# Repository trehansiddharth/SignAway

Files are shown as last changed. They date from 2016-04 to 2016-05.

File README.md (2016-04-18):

# SignAway

SignAway is a completely handheld probe that you can swipe over two signatures to algorithmically verify that they came from the same person. It is my final project for MIT's 6.115 course (Microcontrollers Lab).

## Directory Structure

- `./Background`: Background information on the algorithms used, such as SLAM and neural networks for signature verification.
- `./Datasheets`: Datasheets for the electronic components.
- `./Designs`: Schematics, board layouts, and CAD sketches for hardware.
- `./Logs`: Pictures, log files, and notes taken during development of SignAway to keep track of things.
- `./Source`: Source code running on the 2051 and PSoC.

## Disclaimer

Right now this is a work in progress. The deadline for completion is the end of May.

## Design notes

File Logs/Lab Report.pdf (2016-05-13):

Siddharth Trehan | 6.115: Final Project

## Goals

1. Make a hand-held probe that can verify whether two signatures match
2. I envision being able to swipe the probe over two signatures to verify whether the signature is correct
3. This probe will grab signatures using the camera/motion sensor provided by the ADNS-9800 laser mouse chip
4. The probe will also be able to provide a “forge” mode that allows the user to forge a pre-recorded signature by following directions on a set of LEDs or similar

## Introduction

I intend to build a portable, hand-held probe that allows you to scan over two signatures and verify whether or not they match. This can be used by, for example, lawyers and mailmen who wish to quickly and systematically verify that the same person signed two documents. The probe should be portable (self-contained, small, and lightweight) and easy to use (simply swipe over the two signatures to verify authenticity).
I am interested in this idea primarily because it is unique and because of the technology it integrates together. As a course 6-2, I not only like figuring out how hardware components fit together, but also how I can solve problems using innovative algorithmic techniques. Here, I get to learn about signature matching using artificial neural networks and different image vision techniques that can identify particular distinctive features in a signature. Ive also recently been interested in optical sensors (which provide both images and motion data) because they seem so widely applicable to anything that moves, so I wanted to learn how to use one with a microcontroller.
Finally, I believe this is a creative solution to the problem of not being able to verify the authenticity of signatures because it is easy-to-use and unintrusive in the daily work of people who might want to verify signatures. Signatures are used universally and on some very important documents. However, just based off of anecdotal evidence, the appropriate time and care is not being taken to verify the authenticity of signatures – often, in restaurants for example, even widely different signatures are taken to be from the same person without much thought. Given the popularity of optical character recognition (OCR) in solving other similar problems, such as automatically processing mailing addresses, I believe that such a combined hardware and software approach to this signature verification problem will be very effective.

## Hardware Overview

The following is a block diagram of the hardware for this project:

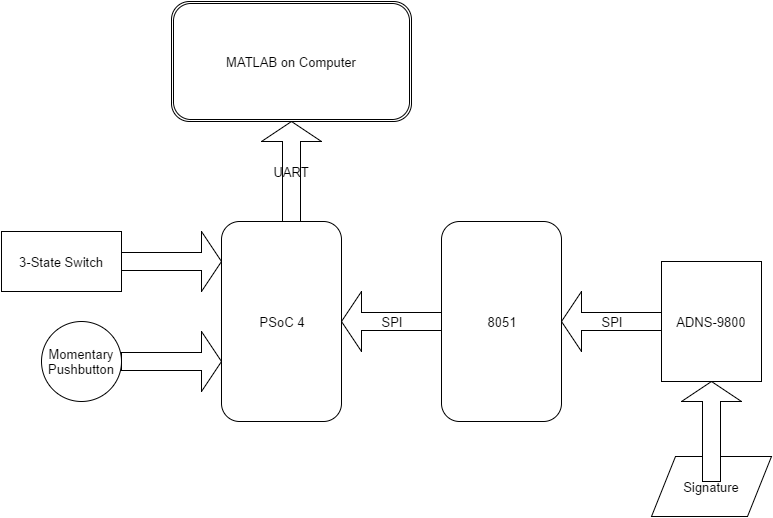
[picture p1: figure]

The ADNS-9800 chip captures the signature (using either motion detection or image capture, as described in the next section). This is communicated over SPI to the 8051, which will filter the signals from the 8051 and do some basic signal processing on them. It will then report only the relevant data to the PSoC. The PSoC also gets signals from a 3-state switch and a momentary pushbutton. The momentary pushbutton is to be held down when capturing a signature, and the position of the 3-state switch will determine what to do with the captured signature. The 3 modes available are “Record”, “Verify”, and “Forge”. The PSoC takes all this information and communicates it to a MATLAB program running on the computer. This MATLAB program is responsible for assimilating information from multiple signatures to either verify them or help you forge them.

## ADNS-9800 Sensor

The ADNS-9800 sensor is a laser mouse sensor that contains a very small camera to track motion over a surface. It works by taking pictures of the surface at a very high frame rate and calculating velocity by running optical flow. I picked this particular chip for its small size, good documentation, and ability to be used as a regular camera. It contains a number of registers, and the SPI protocol is used to read from and write to specific registers. There are three steps in getting the ADNS-9800 sensor working:

1. Wiring up the chip
2. Implementing the SPI protocol
3. Communicating with the chip’s registers

### Wiring up the chip

The following is a diagram and pin labeling of the ADNS-9800 chip:

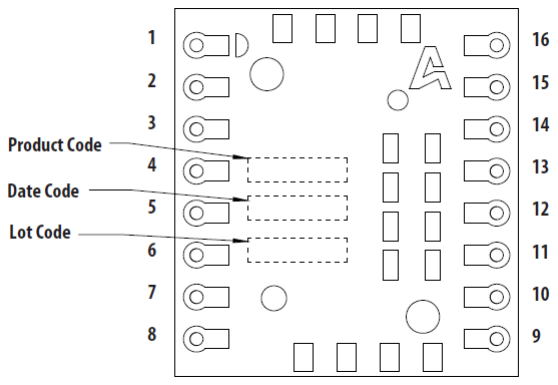
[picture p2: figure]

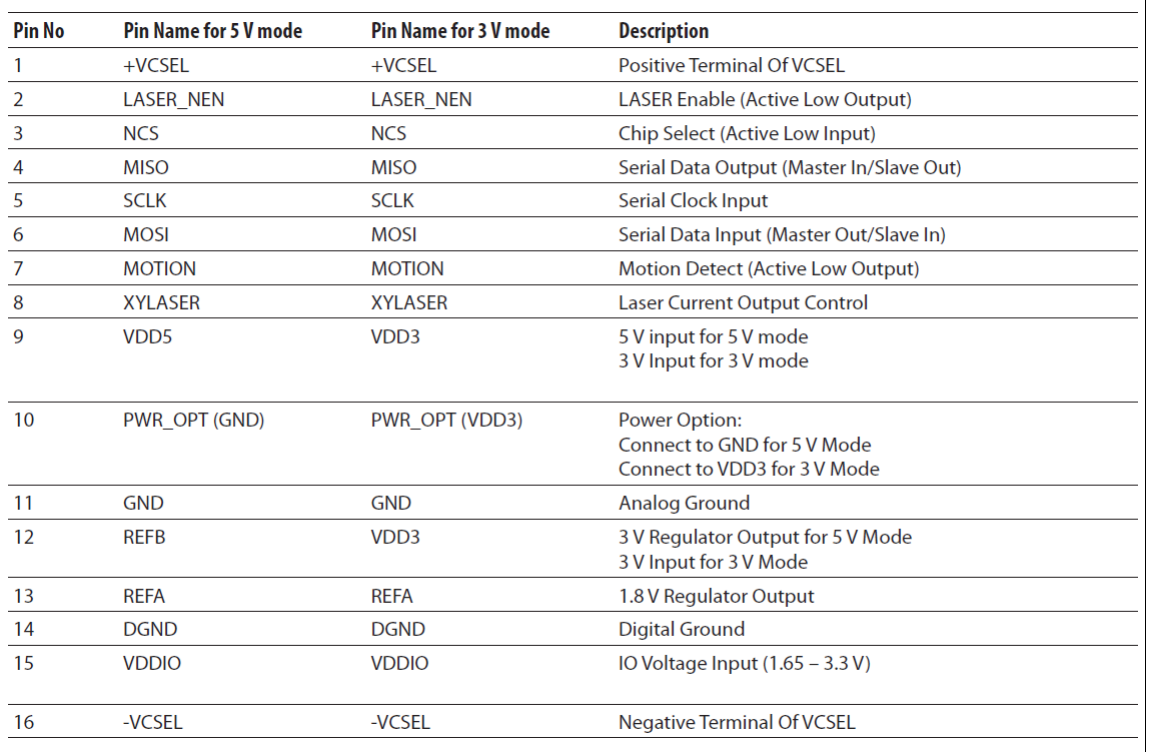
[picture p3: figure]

The ADNS-9800 can run in both 5V and 3V mode. In 5V mode, you provide 5V to VDD5 and GND to PWR OPT, and an internal regulator in the ADNS-9800 chip will provide 3V to provide voltage signals to the other pins. In 3V mode, you provide 3V to VDD3 and 3V to PWR OPT – you are responsible for providing the 3V yourself.

Pins 2-6 (NCS, MISO, SCLK, and MOSI) are used in SPI communication and can be left floating when just trying to get the chip wired up properly. Pin 7 (MOTION) is another pin used for communicating with the microcontroller – it goes high whenever the chip detects motion. In my informal testing when I got the chip wired up, MOTION would go high whenever I placed my finger on the lens. GND and DGND are both wired to ground, and in 3 V mode (which is what I would be using, and the reason will be explained later), VDD3 is wired to 3 V and PWR OPT and REFB are wired to VDD3. REFA (pin 13) is a 1.8 V regulator output and can be ignored.

This leaves the following pins: +VCSEL (pin 1), LASER NEN (pin 2), XYLASER (pin 8), VDDIO (pin 15), and -VCSEL (pin 16). LASER NEN and XYLASER relate to the operation of the laser, which has to be on in order for the mouse to illuminate the surface and capture images. A microcontroller communicating via SPI sets the appropriate register value to enable or disable the laser. This will set LASER NEN to low, which will activate a FET. This will allow XYLASER to draw power from the power supply and activate the laser. The other pins also serve different purposes and their wiring is described in more detail in the datasheet for the ADNS-9800.

The following is a schematic for the breakout board that I used for the ADNS-9800 chip:

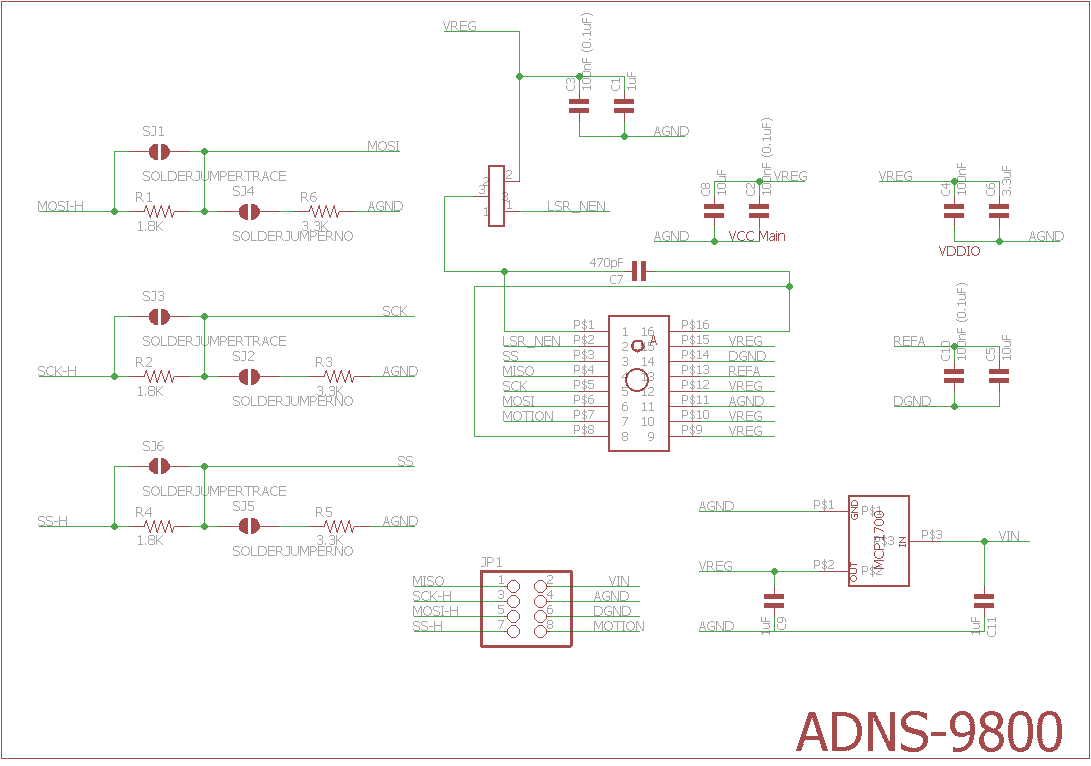
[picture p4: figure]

However, the issue here is that it cannot be used in 5 V mode because the voltage divider at MOSI-H, SCK-H, and SS-H do not actually divide unbuffered voltage. The pin of the 8051 contains an internal pull-up resistor which makes this voltage divider not divide voltage properly. To get around this I ran this breakout board in its native 3V and made a 5-to-3V level converter myself. The following is a schematic for the 5-to-3 TTL converter:

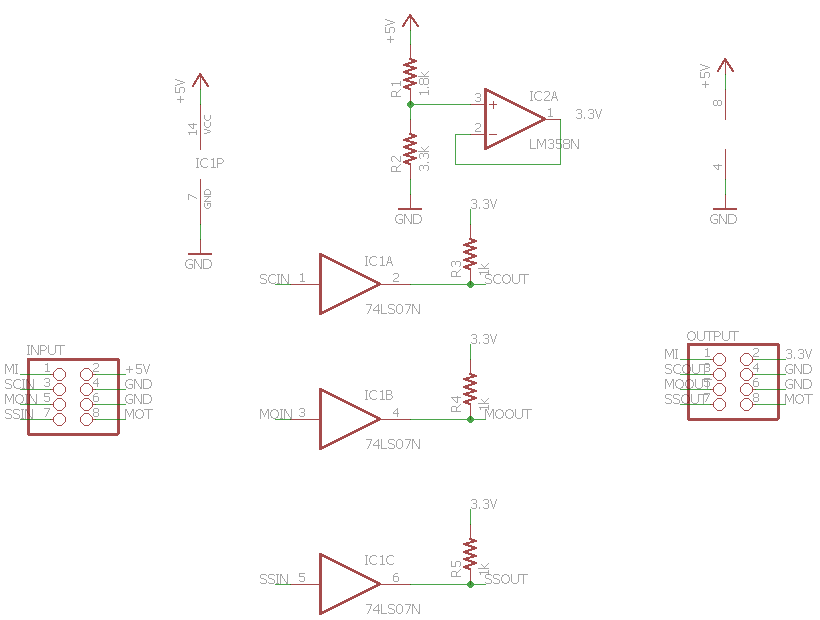
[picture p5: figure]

This contains an op-amp for converting 5V to 3V, and 3 buffers from the 74LS07 open-collector-output chip to perform the level conversion. This setup got the chip working at the right TTL level.

### Implementing the SPI protocol

The ADNS-9800 chip uses the SPI protocol with a max clock frequency of 2 MHz to communicate register values with a microcontroller. The data direction is MSB to LSB, an inactive SCLK signal is high, and data is read by the chip on rising clock edges. There are four types of commands:

1. Write operations: 16 bits are sent over MOSI. The first byte indicates the address of the register to write, and the second byte indicates the data to write to register. The first bit in the signal is 1 to indicate that it is a write command.
2. Read operations: 8 bits are sent over MOSI and 8 bits are received over MISO. The byte sent over MOSI indicates the address of the register to read (with the first bit a 0 to indicate reading), and the byte received over MISO is the data contained in the register. There is a also a required timing between sending the first byte and receiving the second.

3. Motion burst operations: In some cases reading each register corresponding to different kinds of motion individually using the read and write operations described above can be too slow. In motion burst operation, the MOTION BURST register is written to once. Then, when it is read using a normal read operation, 14 bytes are returned instead of 1, corresponding to the values of 14 different motion-related registers instead of just 1 at a time.
4. Image burst operations: Image burst mode allows you to download an entire frame that the chip has most recently captured. Since each frame is 30-by-30, this means transferring 900 8-bit pixel values over SPI. In this operation, you must first write to the FRAME CAPTURE register twice, read the MOTION bit register until the LSB is set, and then read 900 bytes from the PIXEL BURST register. This mode, however, disables motion tracking and requires a hardware reset. Therefore, switching back and forth between motion burst mode and image burst mode is not entirely practical.

Write operations

The following is a timing diagram for this operation:

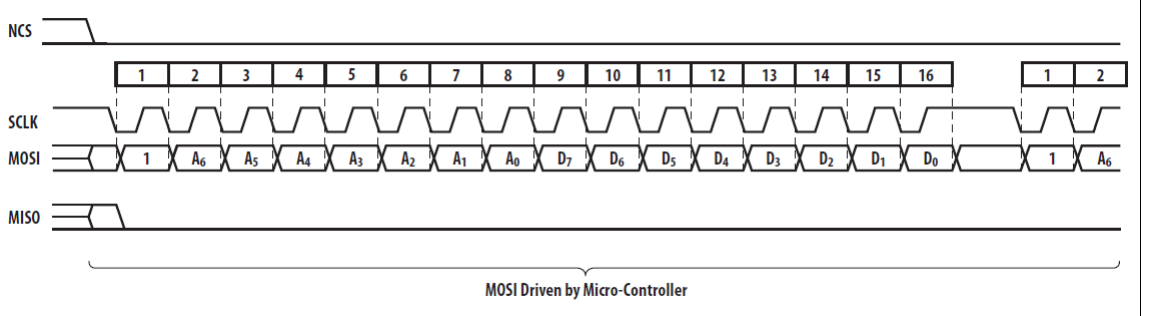
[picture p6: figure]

I implemented this by first writing the read spi and write spi subroutines on my microcontroller. These two subroutines drive an SCLK signal and either write a byte over MOSI or read a byte over MISO. They do not drive the SS pin low; that must be done in a higher level subroutine that takes into account which slave to select.

The following is an SCLK waveform I got on read spi:

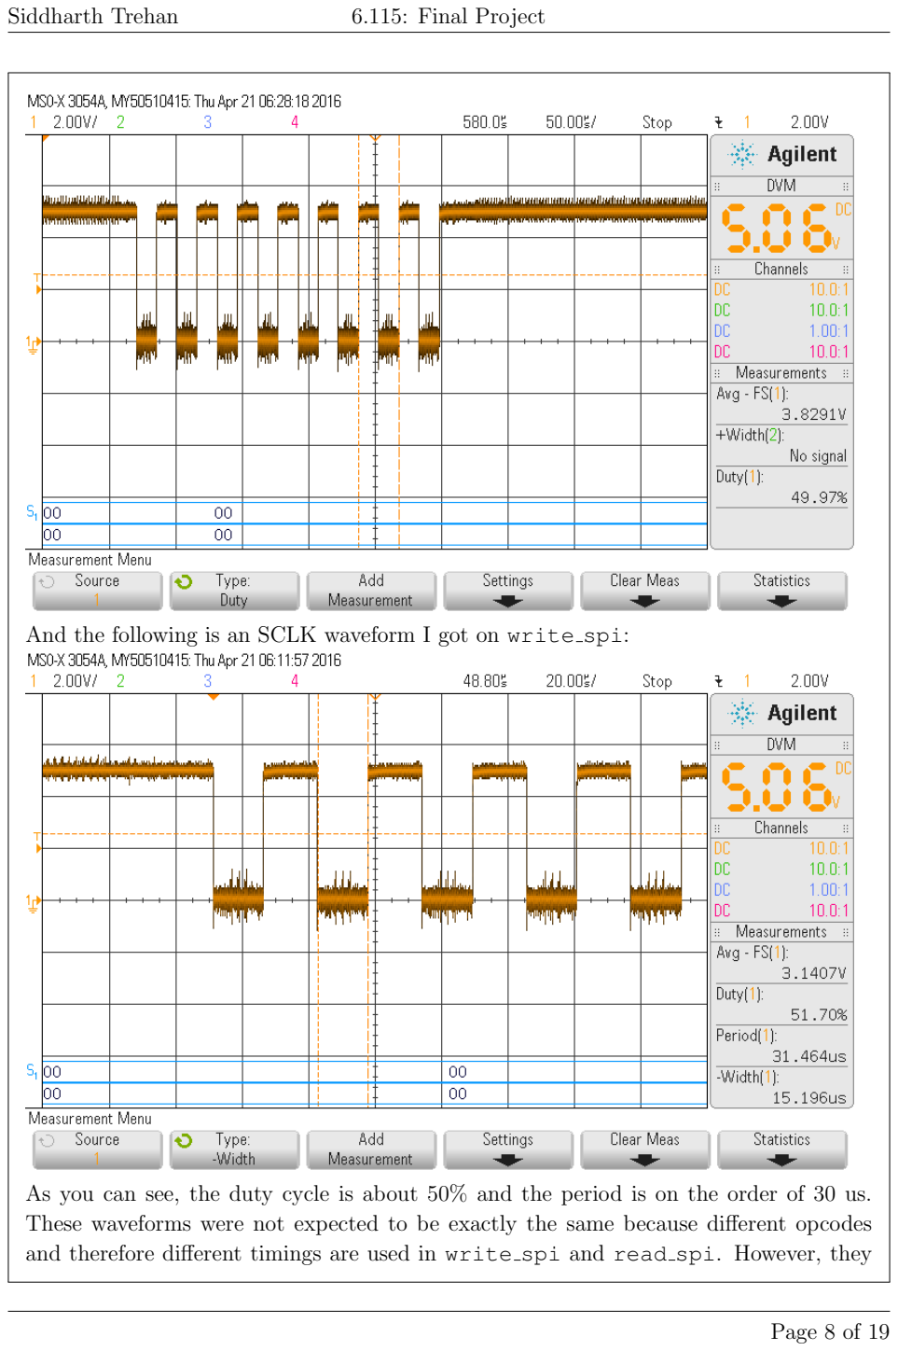
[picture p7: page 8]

And the following is an SCLK waveform I got on write spi:

As you can see, the duty cycle is about 50% and the period is on the order of 30 us. These waveforms were not expected to be exactly the same because different opcodes and therefore different timings are used in write spi and read spi. However, they do fit the requirements of the ADNS-9800 chip. I later modified these to have a smaller period by giving up on the duty cycle having to be 50% with the same result in terms of SPI operations but a slightly faster transfer rate.

Next, I implemented the write adns subroutine, which performs a write operation on the ADNS-9800 chip. It lowers NCS, does a write spi to write the register address over MOSI (with the MSB set to 1), then another write spi to write the register value over MOSI, and then finally raises NCS. I got the following waveforms for the SCLK and MOSI lines:

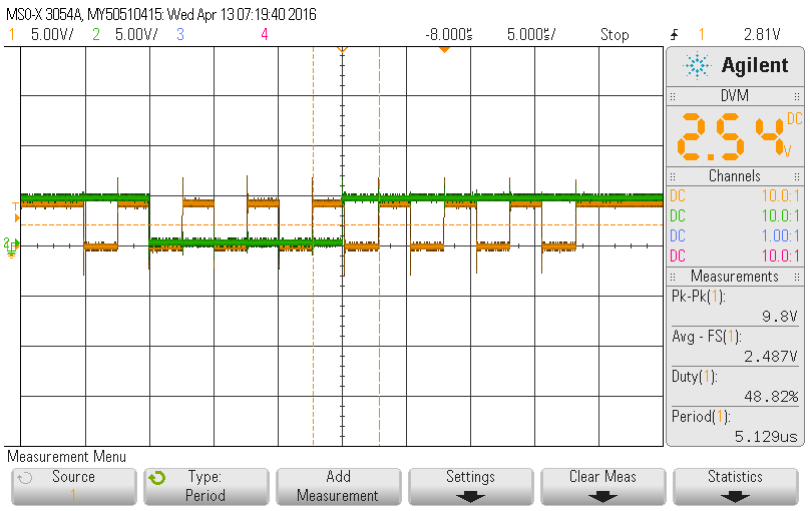
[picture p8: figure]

And I got the following writing the value #0F5h to register #00h:

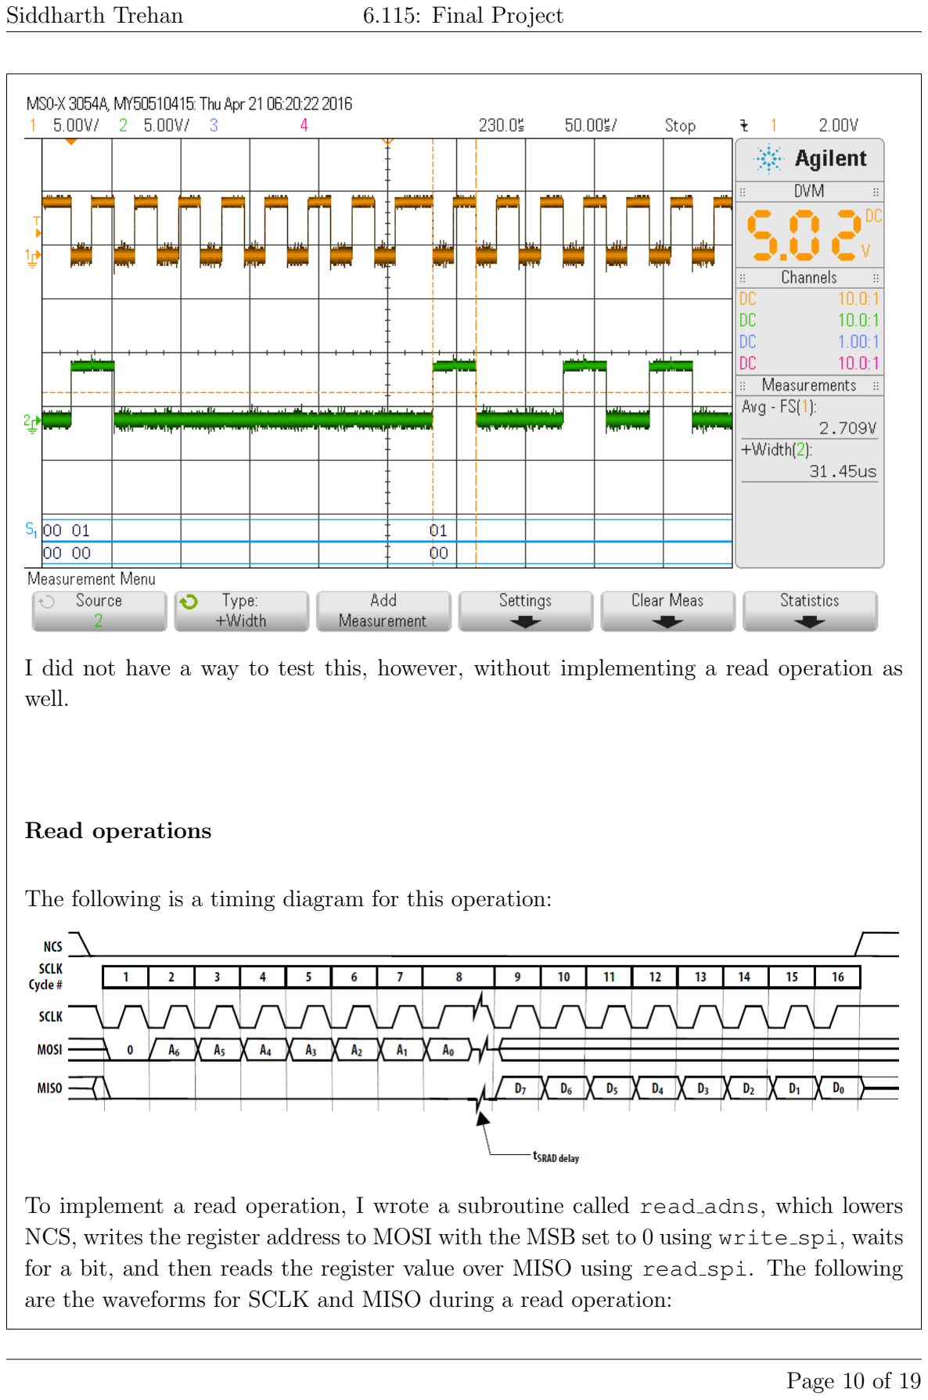
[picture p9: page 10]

I did not have a way to test this, however, without implementing a read operation as well.

Read operations

The following is a timing diagram for this operation:

To implement a read operation, I wrote a subroutine called read adns, which lowers NCS, writes the register address to MOSI with the MSB set to 0 using write spi, waits for a bit, and then reads the register value over MISO using read spi. The following are the waveforms for SCLK and MISO during a read operation:

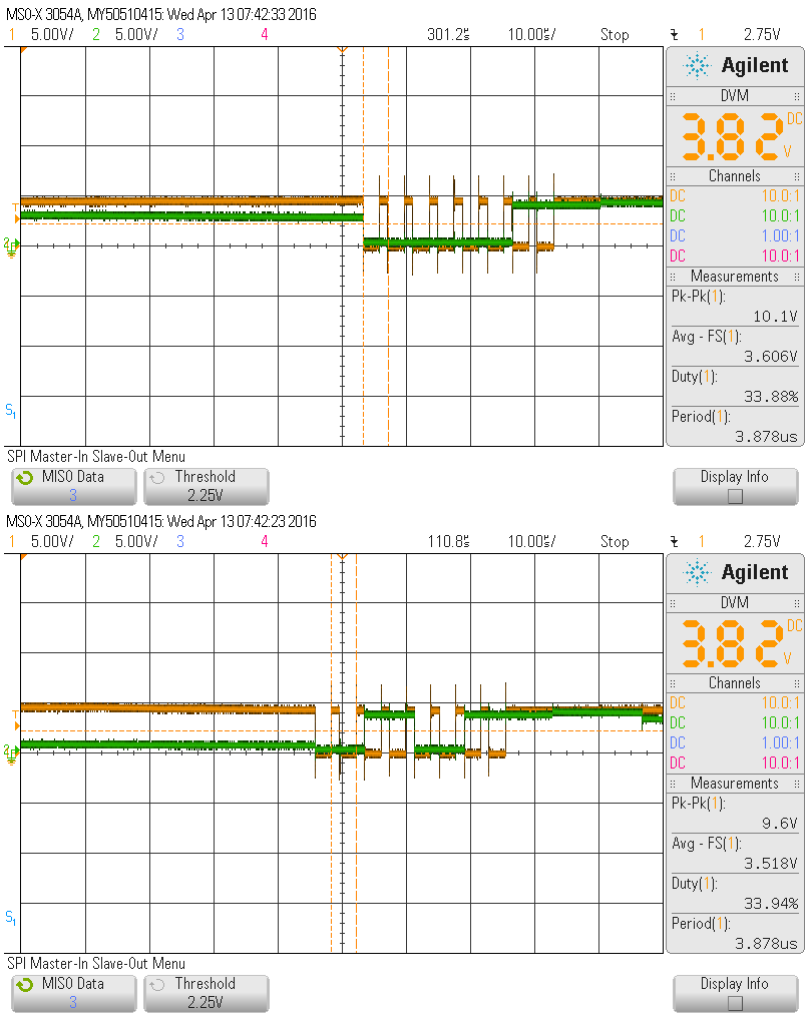
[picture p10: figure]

These two diagrams are reads of registers #01h and #00h, respectively, which the datasheet says should always have the values #03h and #33h, respectively. As you can see above, this is indeed confirmed by the scope.
To test the write operation, I wrote to a register and tested whether read returned that same value. It did, so I was confident that the write operation worked.

Motion burst operations

The following is a timing diagram for this operation:

The way I implemented motion burst mode was to:

1. Designate a 14-byte portion of the RAM where the data from the 14 registers read will be stored consecutively
2. Write a subroutine called burst that continuously calls read spi and writes bytes consecutively to a portion of RAM until a specified position in memory is reached
3. Write a subroutine called motion burst that takes care of writing to the MO-TION BURST register, lowering NCS, etc.

Running motion burst mode requires the laser to be turned on, which will be described in a later section.

Image burst operations

The following is a timing diagram for this operation:

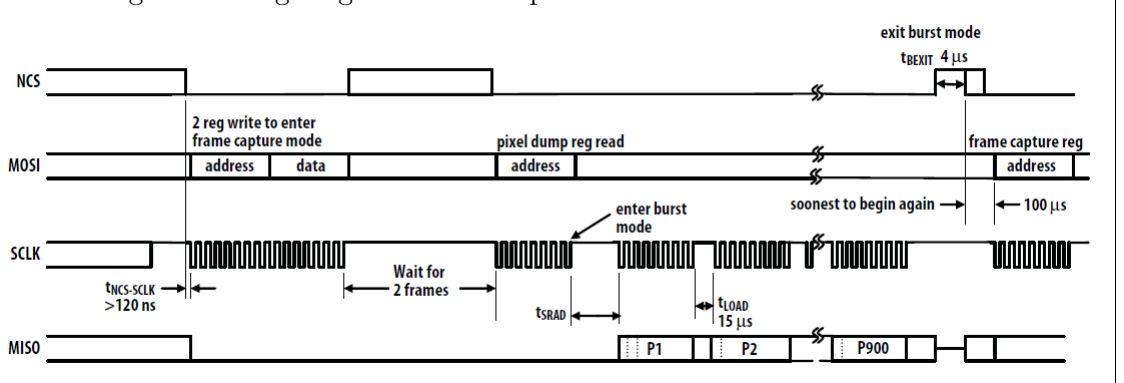
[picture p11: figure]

In this mode, 900 pixels are to be transferred. I again reused the burst subroutine I wrote for motion burst mode. I designated a 900-byte part of RAM to store a frame and wrote a subroutine called image burst to read and write to the appropriate registers (according to the timing diagram above) and call the burst subroutine to store all the values read over SPI to RAM.

Running image burst mode also requires the laser to be turned on as well as a hardware reset, which will also be described in a later section.

To test that this code works, I printed out the 900 pixel values over the serial port and wrote a MATLAB script called viewImage.m that takes in 900 pixel values and shows you an image reconstructing it. At first, I saw only very dark frames because the spacing between the lens and surface was not correct. The following is an example of such an image after constructing my mechanicals to have the right lens height and after modifying the visualization algorithm to normalize pixel brightness, taken over a 5 dollar bill and over my driver’s license, respectively:

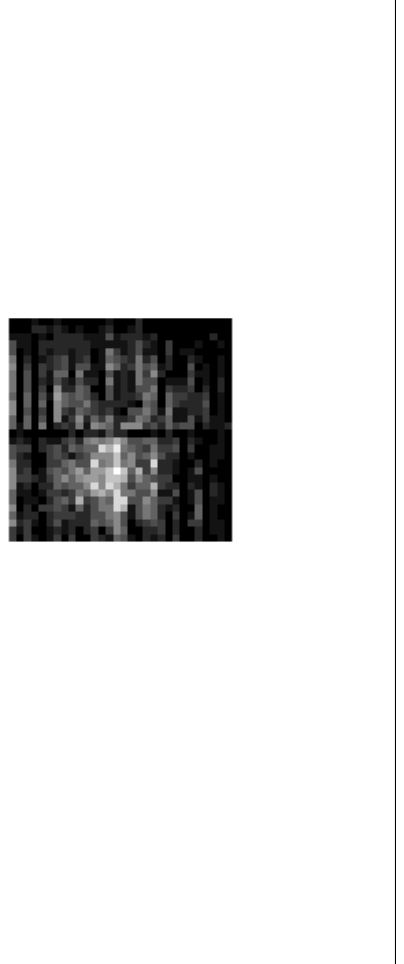
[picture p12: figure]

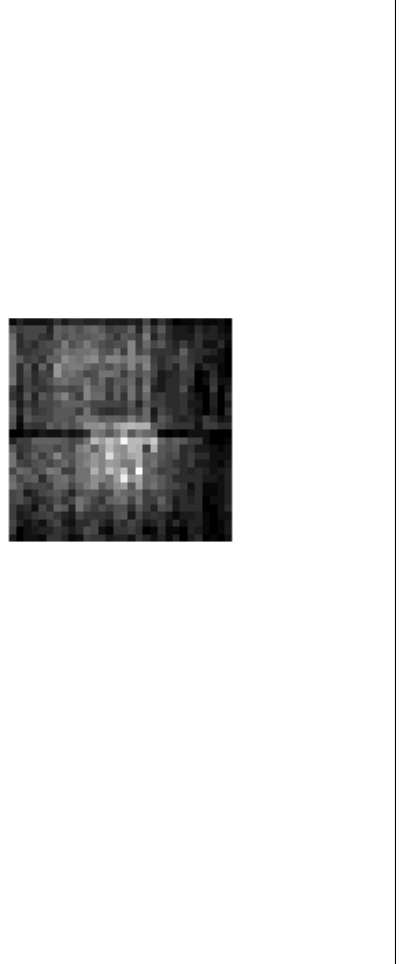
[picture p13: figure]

As you can see, what is in the image is not very clear, the resolution is low, the result is noisy, and the physical window size is very small (only about a square millimeter). For these reasons, I decided to stick with recording pen motion instead of capturing the signature using a camera.

Testing

To test whether my communication with the chip worked, I made a repl that supported the following operations:

1. R: Read a register and print out its value
2. W: Write to a register
3. M: Perform a motion burst capture and print out the values of the 14 registers that we get
4. I: Perform an image capture and print out the values of all 900 pixels that we get

5. P: Perform a power-up sequence (reset the hardware and enable the laser)

This helped me with my next task, which was to figure out what different operations did and test them out before I coded them.

### Communicating with the chip’s registers

The next step in getting the ADNS-9800 working was to figure out what the different registers mean and how to perform operations such as power-up and laser enable. The following is a table of the registers relevant to my project and their description:

Register Name | Address | Description | Remarks
Motion | 02h | Contains information about whether motion or image capture data is available | Motion data is available if MSB is set to 1, an image frame is available if LSB is set to 1. Reading this register freezes Delta * values.
Delta X L | 03h | Lower byte of accumulated motion in X direction since the last read | Reading it clears the MSB of MOTION and resets the value of this register
Delta X H | 04h | Upper byte of accumulated motion in X direction since the last read | Reading it clears the MSB of MOTION and resets the value of this register
Delta Y L | 05h | Lower byte of accumulated motion in Y direction since the last read | Reading it clears the MSB of MOTION and resets the value of this register
Delta Y H | 06h | Upper byte of accumulated motion in Y direction since the last read | Reading it clears the MSB of MOTION and resets the value of this register
Configuration I | 0fh | Resolution of the ADNS sensor in terms of how many counts are reported per inch travelled | Resolution of the sensor in CPI is the value of this register times 200
Frame Capture | 12h | Used to capture the next complete frame of 900 pixels during image burst mode | Writing to this register starts image burst
Laser CTRL0 | 20h | Used to turn the laser on and off | Setting the LSB to 1 disables the laser and setting it to 0 enables it
Power Up Reset | 3ah | Used to reset the chip (set all registers to their default values) | Write 5ah to this register to start up or to exit image burst mode
Motion Burst | 50h | Used to capture the values of 14 motion-related registers at once | Reading this register grabs all 14 values at once
Pixel Burst | 64h | Used to capture the next complete frame of 900 pixels during image burst mode | Reading this register grabs all 900 pixel values at once

## Mechanicals

The next step was to construct the mechanicals with the following goals in mind:

1. Optimize the distance between the sensor and the reading surface as to allow max-imum motion pickup
2. Attach to a pen-holding device that allows you to write while tracking motion
3. Have an easily-holdable button on the side that you can press and hold to record the signature
4. Have a 3-state switch that allows you to flip between RECORD, VERIFY, and FORGE modes

I did my designs in Solidworks and 3-D printed the parts.

8051

On the 8051 I wrote code that would communicate via SPI with both the ADNS-9800 and the PSoC. In this system, it is the master to the ADNS-9800 and the master to the PSoC. It communicates with both by flipping the right slave-select line.
Furthermore, I had some basic signal processing on my 8051. In its main loop, the 8051:
1. Polls the ADNS-9800 in motion burst mode
2. Updates a displacement counter
3. If the manhattan distance for the displacement exceeds a certain quantity, it clears the displacement counter and reports a hit to the PSoC

In this way, the 8051 acts as a software-based 2-dimensional Schmitt trigger. We can imagine that the reading surface is broken down into a grid of diamonds (diamonds are the “circles” in Manhattan space). By using the above algorithm, we can clearly see that the threshold for traveling to the next grid cell is different from the threshold for moving back. This acts as to “debounce” the optical sensor motion.

## PSoC

On the PSoC, I have an SPI slave unit, a UART unit, and multiple pins to receive signals from the button and switch. This reports data to MATLAB over UART.

## MATLAB

I tried two different approaches to verifying the signature:

1. Center and normalize the signature by comparing mean and standard deviation. Compute average sum-of-square displacement of points.
2. Center and normalize signature by comparing mean and standard deviation. Compute angle displacements at each joint required to match the signatures together.

The first approach worked better. The following are signatures of my own name that I captured:

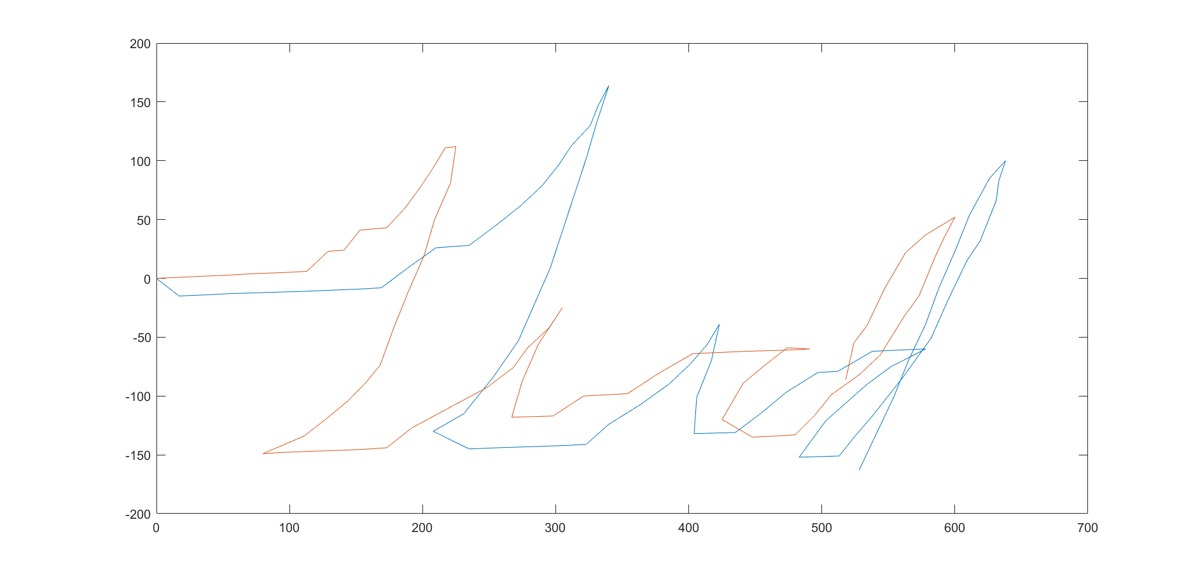
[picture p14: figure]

And the following is the signatures normalized:

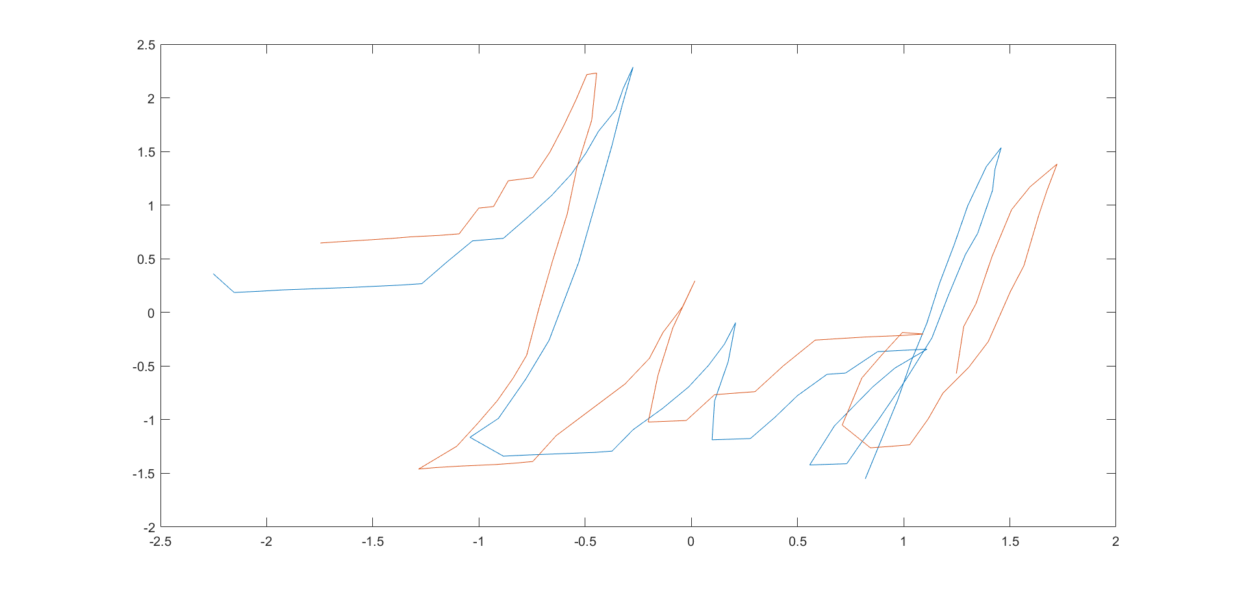
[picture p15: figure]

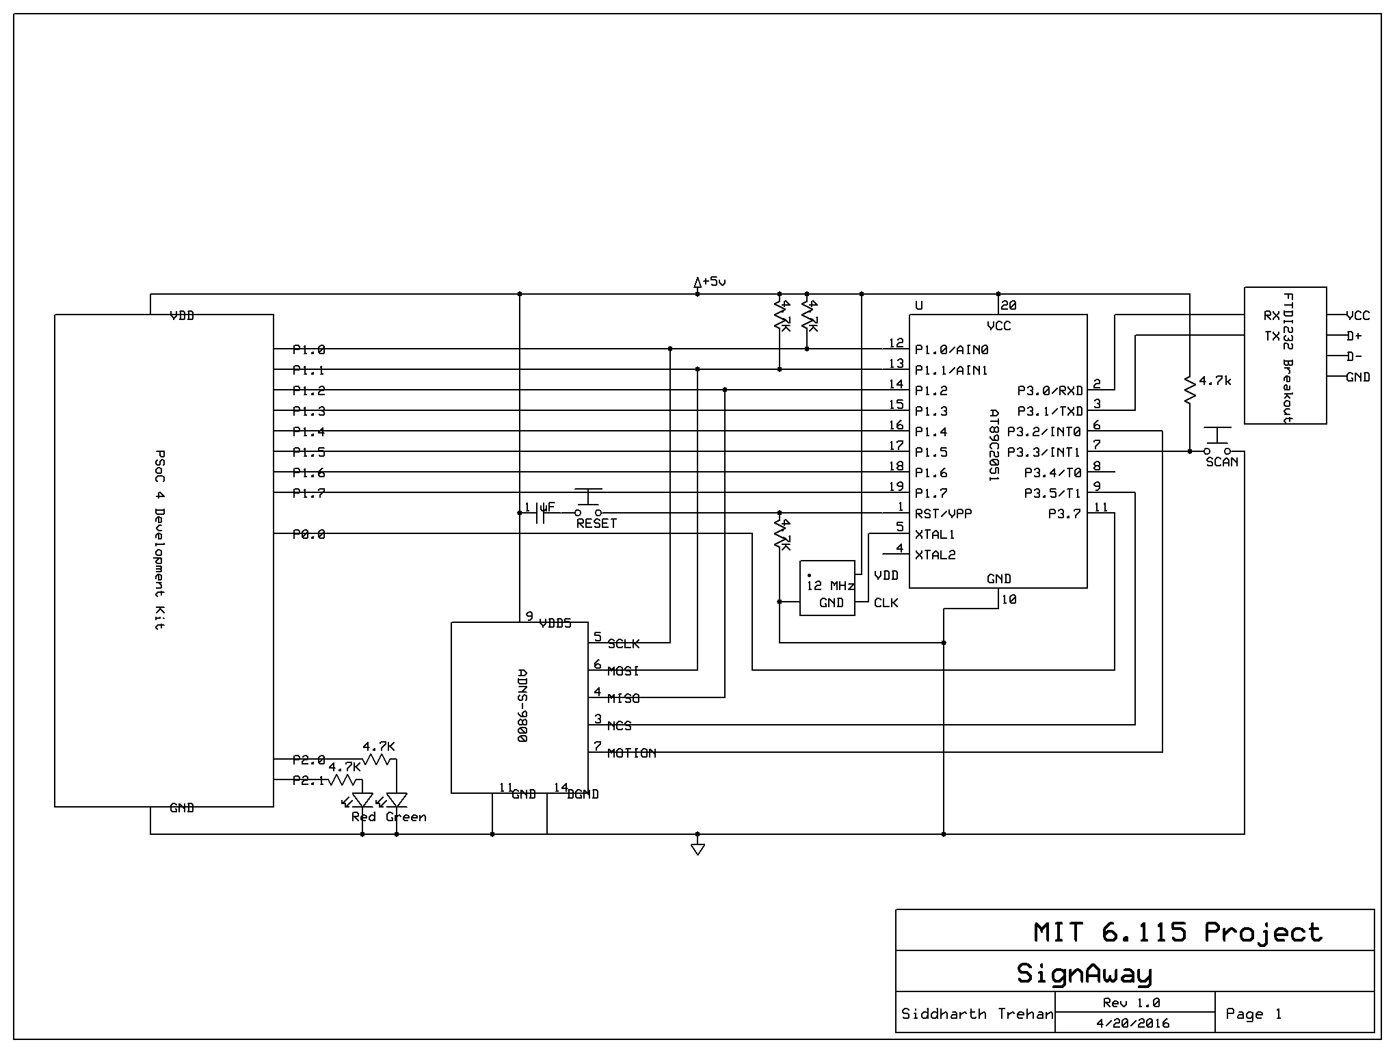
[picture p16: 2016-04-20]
Designs/Whole Board.bmp

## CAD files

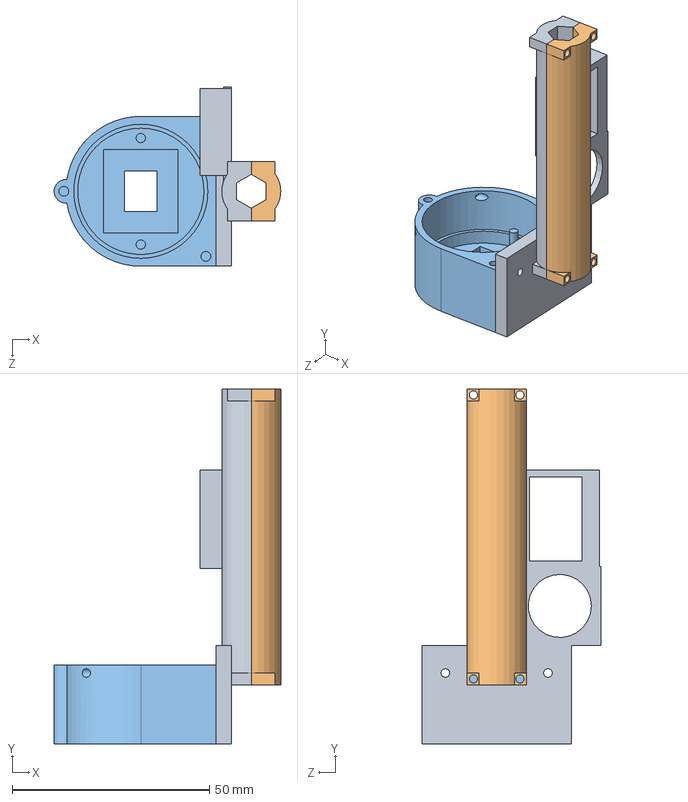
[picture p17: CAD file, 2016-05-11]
Designs/Full Probe.SLDASM
57.5 x 90.0 x 45.5 mm
Probe Left
Probe Right
Base

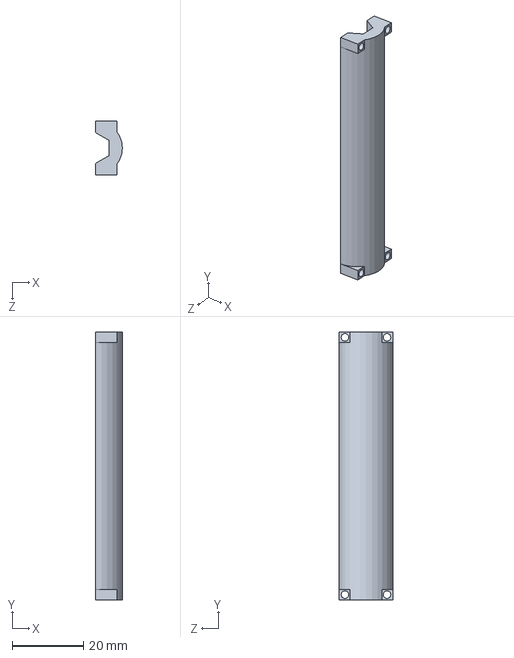
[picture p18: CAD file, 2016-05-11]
Designs/Probe Right.SLDPRT
7.50 x 75.0 x 15.0 mm

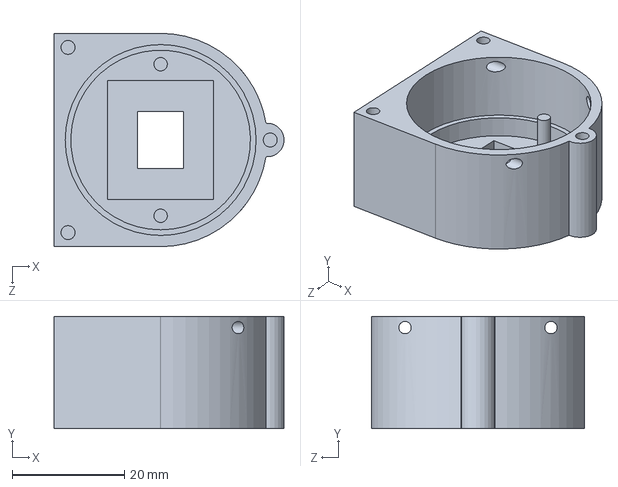
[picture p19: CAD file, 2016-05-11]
Designs/Base.SLDPRT
41.0 x 20.0 x 38.0 mm

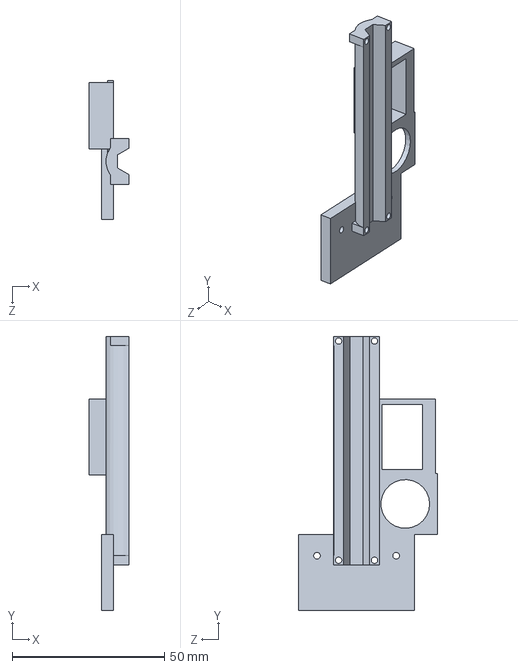
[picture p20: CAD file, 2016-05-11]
Designs/Probe Left.SLDPRT
13.0 x 90.0 x 45.5 mm

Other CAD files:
Designs/Base.STL
Designs/Probe Left.STL
Designs/Probe Right.STL

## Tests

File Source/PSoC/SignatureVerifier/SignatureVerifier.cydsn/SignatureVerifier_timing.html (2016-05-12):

# Static Timing Analysis

Project : | SignatureVerifier
Build Time : | 05/11/16 19:49:49
Device : | CY8C4245AXI-483
Temperature : | -40C - 85C
VDDA : | 3.30
VDDD : | 3.30
Voltage : | 3.3

Expand All | Collapse All | Show All Paths | Hide All Paths

+ Timing Violation Section

Note: If your design will only ever run at typical room temperatures, selecting the narrower temperature range in the system DWR for your application helps the tool to find timing-compliant routing solutions.

Violation | Source Clock | Destination Clock | Slack(ns)
Hold
| CyHFCLK | Pin_SCLK(0)/fb | -2.029

+ Clock Summary Section

Clock | Domain | Nominal Frequency | Required Frequency | Maximum Frequency | Violation
CyHFCLK | CyHFCLK | 24.000 MHz | 24.000 MHz | 81.500 MHz
SPI_Clock | CyHFCLK | 12.000 MHz | 12.000 MHz | 86.281 MHz
UART_SCBCLK | CyHFCLK | 115.385 kHz | 115.385 kHz | N/A
Pin_SCLK(0)/fb | CyHFCLK | UNKNOWN | UNKNOWN | 34.516 MHz
CyILO | CyILO | 32.000 kHz | 32.000 kHz | N/A
CyIMO | CyIMO | 24.000 MHz | 24.000 MHz | N/A
CyLFCLK | CyLFCLK | 32.000 kHz | 32.000 kHz | N/A
CySYSCLK | CySYSCLK | 24.000 MHz | 24.000 MHz | N/A
UART_SCBCLK(FFB) | UART_SCBCLK(FFB) | 115.385 kHz | 115.385 kHz | N/A

+ Register to Register Section

+ Setup Subsection

+ Source Clock : CyHFCLK : Positive edge(Required Frequency 24 MHz)

+ Destination Clock : Pin_SCLK(0)/fb : Positive edge

Path Delay Requirement : 41.6667ns

Affects clock : CyHFCLK

Source | Destination | FMax | Delay (ns) | Slack (ns) | Violation
Pin_MOSI(0)/fb | \SPI:BSPIS:es3:SPISlave:mosi_tmp\/main_0 | 244.200 MHz | 4.095 | 37.572

Type | Location | Fanout | Instance/Net | Source | Dest | Delay (ns)
iocell9 | P0[0] | 1 | Pin_MOSI(0) | Pin_MOSI(0)/in_clock | Pin_MOSI(0)/fb | 4.047
Route | | 1 | Net_27 | Pin_MOSI(0)/fb | \SPI:BSPIS:es3:SPISlave:mosi_tmp\/main_0 | 5.211
macrocell7 | U(1,0) | 1 | \SPI:BSPIS:es3:SPISlave:mosi_tmp\ | | SETUP | 3.510
Clock | | | | | Skew | -8.673

+ Destination Clock : Pin_SCLK(0)/fb : Negative edge

Path Delay Requirement : 41.6667ns

Affects clock : CyHFCLK

Source | Destination | FMax | Delay (ns) | Slack (ns) | Violation
Pin_SS(0)/fb | \SPI:BSPIS:es3:SPISlave:BitCounter\/enable | 81.500 MHz | 12.270 | 29.397

Type | Location | Fanout | Instance/Net | Source | Dest | Delay (ns)
iocell11 | P0[2] | 1 | Pin_SS(0) | Pin_SS(0)/in_clock | Pin_SS(0)/fb | 4.047
Route | | 1 | Net_29 | Pin_SS(0)/fb | \SPI:BSPIS:es3:SPISlave:inv_ss\/main_0 | 5.601
macrocell4 | U(1,0) | 1 | \SPI:BSPIS:es3:SPISlave:inv_ss\ | \SPI:BSPIS:es3:SPISlave:inv_ss\/main_0 | \SPI:BSPIS:es3:SPISlave:inv_ss\/q | 3.350
Route | | 1 | \SPI:BSPIS:es3:SPISlave:inv_ss\ | \SPI:BSPIS:es3:SPISlave:inv_ss\/q | \SPI:BSPIS:es3:SPISlave:BitCounter\/enable | 4.605
count7cell | U(1,0) | 1 | \SPI:BSPIS:es3:SPISlave:BitCounter\ | | SETUP | 3.340
Clock | | | | | Skew | -8.673
Pin_SS(0)/fb | \SPI:BSPIS:es3:SPISlave:sR16:Dp:u0\/cs_addr_2 | 89.302 MHz | 11.198 | 30.469

Type | Location | Fanout | Instance/Net | Source | Dest | Delay (ns)
iocell11 | P0[2] | 1 | Pin_SS(0) | Pin_SS(0)/in_clock | Pin_SS(0)/fb | 4.047
Route | | 1 | Net_29 | Pin_SS(0)/fb | \SPI:BSPIS:es3:SPISlave:inv_ss\/main_0 | 5.601
macrocell4 | U(1,0) | 1 | \SPI:BSPIS:es3:SPISlave:inv_ss\ | \SPI:BSPIS:es3:SPISlave:inv_ss\/main_0 | \SPI:BSPIS:es3:SPISlave:inv_ss\/q | 3.350
Route | | 1 | \SPI:BSPIS:es3:SPISlave:inv_ss\ | \SPI:BSPIS:es3:SPISlave:inv_ss\/q | \SPI:BSPIS:es3:SPISlave:sR16:Dp:u0\/cs_addr_2 | 3.703
datapathcell1 | U(1,0) | 1 | \SPI:BSPIS:es3:SPISlave:sR16:Dp:u0\ | | SETUP | 3.170
Clock | | | | | Skew | -8.673
Pin_SS(0)/fb | \SPI:BSPIS:es3:SPISlave:sR16:Dp:u1\/cs_addr_2 | 89.326 MHz | 11.195 | 30.472

Type | Location | Fanout | Instance/Net | Source | Dest | Delay (ns)
iocell11 | P0[2] | 1 | Pin_SS(0) | Pin_SS(0)/in_clock | Pin_SS(0)/fb | 4.047
Route | | 1 | Net_29 | Pin_SS(0)/fb | \SPI:BSPIS:es3:SPISlave:inv_ss\/main_0 | 5.601
macrocell4 | U(1,0) | 1 | \SPI:BSPIS:es3:SPISlave:inv_ss\ | \SPI:BSPIS:es3:SPISlave:inv_ss\/main_0 | \SPI:BSPIS:es3:SPISlave:inv_ss\/q | 3.350
Route | | 1 | \SPI:BSPIS:es3:SPISlave:inv_ss\ | \SPI:BSPIS:es3:SPISlave:inv_ss\/q | \SPI:BSPIS:es3:SPISlave:sR16:Dp:u1\/cs_addr_2 | 3.701
datapathcell2 | U(0,0) | 1 | \SPI:BSPIS:es3:SPISlave:sR16:Dp:u1\ | | SETUP | 3.170
Clock | | | | | Skew | -8.674
Pin_MOSI(0)/fb | \SPI:BSPIS:es3:SPISlave:sR16:Dp:u0\/route_si | 97.220 MHz | 10.286 | 31.381

Type | Location | Fanout | Instance/Net | Source | Dest | Delay (ns)
iocell9 | P0[0] | 1 | Pin_MOSI(0) | Pin_MOSI(0)/in_clock | Pin_MOSI(0)/fb | 4.047
Route | | 1 | Net_27 | Pin_MOSI(0)/fb | \SPI:BSPIS:es3:SPISlave:mosi_to_dp\/main_0 | 5.211
macrocell8 | U(1,0) | 1 | \SPI:BSPIS:es3:SPISlave:mosi_to_dp\ | \SPI:BSPIS:es3:SPISlave:mosi_to_dp\/main_0 | \SPI:BSPIS:es3:SPISlave:mosi_to_dp\/q | 3.350
Route | | 1 | \SPI:BSPIS:es3:SPISlave:mosi_to_dp\ | \SPI:BSPIS:es3:SPISlave:mosi_to_dp\/q | \SPI:BSPIS:es3:SPISlave:sR16:Dp:u0\/route_si | 2.701
datapathcell1 | U(1,0) | 1 | \SPI:BSPIS:es3:SPISlave:sR16:Dp:u0\ | | SETUP | 3.650
Clock | | | | | Skew | -8.673
Pin_SS(0)/fb | \SPI:BSPIS:es3:SPISlave:BitCounter\/reset | 1046.025 MHz | 0.956 | 40.711

Type | Location | Fanout | Instance/Net | Source | Dest | Delay (ns)
iocell11 | P0[2] | 1 | Pin_SS(0) | Pin_SS(0)/in_clock | Pin_SS(0)/fb | 4.047
Route | | 1 | Net_29 | Pin_SS(0)/fb | \SPI:BSPIS:es3:SPISlave:BitCounter\/reset | 5.582
count7cell | U(1,0) | 1 | \SPI:BSPIS:es3:SPISlave:BitCounter\ | | RECOVERY | -0.000
Clock | | | | | Skew | -8.673

+ Source Clock : Pin_SCLK(0)/fb : Positive edge

+ Destination Clock : Pin_SCLK(0)/fb : Negative edge

Path Delay Requirement : 41.6667ns

Source | Destination | FMax | Delay (ns) | Slack (ns) | Violation
\SPI:BSPIS:es3:SPISlave:mosi_tmp\/q | \SPI:BSPIS:es3:SPISlave:sR16:Dp:u0\/route_si | 69.032 MHz | 14.486

Type | Location | Fanout | Instance/Net | Source | Dest | Delay (ns)
macrocell7 | U(1,0) | 1 | \SPI:BSPIS:es3:SPISlave:mosi_tmp\ | \SPI:BSPIS:es3:SPISlave:mosi_tmp\/clock_0 | \SPI:BSPIS:es3:SPISlave:mosi_tmp\/q | 1.250
Route | | 1 | \SPI:BSPIS:es3:SPISlave:mosi_tmp\ | \SPI:BSPIS:es3:SPISlave:mosi_tmp\/q | \SPI:BSPIS:es3:SPISlave:mosi_to_dp\/main_5 | 2.228
macrocell8 | U(1,0) | 1 | \SPI:BSPIS:es3:SPISlave:mosi_to_dp\ | \SPI:BSPIS:es3:SPISlave:mosi_to_dp\/main_5 | \SPI:BSPIS:es3:SPISlave:mosi_to_dp\/q | 3.350
Route | | 1 | \SPI:BSPIS:es3:SPISlave:mosi_to_dp\ | \SPI:BSPIS:es3:SPISlave:mosi_to_dp\/q | \SPI:BSPIS:es3:SPISlave:sR16:Dp:u0\/route_si | 2.701
datapathcell1 | U(1,0) | 1 | \SPI:BSPIS:es3:SPISlave:sR16:Dp:u0\ | | SETUP | 3.650
Clock | | | | | Skew | 1.307

+ Source Clock : Pin_SCLK(0)/fb : Negative edge

+ Destination Clock : Pin_SCLK(0)/fb : Positive edge

Path Delay Requirement : 41.6667ns

Source | Destination | FMax | Delay (ns) | Slack (ns) | Violation
\SPI:BSPIS:es3:SPISlave:BitCounter\/count_0 | \SPI:BSPIS:es3:SPISlave:sR16:Dp:u0\/f1_load | 82.994 MHz | 12.049

Type | Location | Fanout | Instance/Net | Source | Dest | Delay (ns)
count7cell | U(1,0) | 1 | \SPI:BSPIS:es3:SPISlave:BitCounter\ | \SPI:BSPIS:es3:SPISlave:BitCounter\/clock_n | \SPI:BSPIS:es3:SPISlave:BitCounter\/count_0 | 2.110
Route | | 1 | \SPI:BSPIS:es3:SPISlave:count_0\ | \SPI:BSPIS:es3:SPISlave:BitCounter\/count_0 | \SPI:BSPIS:es3:SPISlave:tx_load\/main_3 | 2.725
macrocell11 | U(1,0) | 1 | \SPI:BSPIS:es3:SPISlave:tx_load\ | \SPI:BSPIS:es3:SPISlave:tx_load\/main_3 | \SPI:BSPIS:es3:SPISlave:tx_load\/q | 3.350
Route | | 1 | \SPI:BSPIS:es3:SPISlave:tx_load\ | \SPI:BSPIS:es3:SPISlave:tx_load\/q | \SPI:BSPIS:es3:SPISlave:sR16:Dp:u0\/f1_load | 2.557
datapathcell1 | U(1,0) | 1 | \SPI:BSPIS:es3:SPISlave:sR16:Dp:u0\ | | SETUP | -0.000
Clock | | | | | Skew | 1.307
\SPI:BSPIS:es3:SPISlave:BitCounter\/count_0 | \SPI:BSPIS:es3:SPISlave:sR16:Dp:u1\/f1_load | 83.008 MHz | 12.047

Type | Location | Fanout | Instance/Net | Source | Dest | Delay (ns)
count7cell | U(1,0) | 1 | \SPI:BSPIS:es3:SPISlave:BitCounter\ | \SPI:BSPIS:es3:SPISlave:BitCounter\/clock_n | \SPI:BSPIS:es3:SPISlave:BitCounter\/count_0 | 2.110
Route | | 1 | \SPI:BSPIS:es3:SPISlave:count_0\ | \SPI:BSPIS:es3:SPISlave:BitCounter\/count_0 | \SPI:BSPIS:es3:SPISlave:tx_load\/main_3 | 2.725
macrocell11 | U(1,0) | 1 | \SPI:BSPIS:es3:SPISlave:tx_load\ | \SPI:BSPIS:es3:SPISlave:tx_load\/main_3 | \SPI:BSPIS:es3:SPISlave:tx_load\/q | 3.350
Route | | 1 | \SPI:BSPIS:es3:SPISlave:tx_load\ | \SPI:BSPIS:es3:SPISlave:tx_load\/q | \SPI:BSPIS:es3:SPISlave:sR16:Dp:u1\/f1_load | 2.556
datapathcell2 | U(0,0) | 1 | \SPI:BSPIS:es3:SPISlave:sR16:Dp:u1\ | | SETUP | -0.000
Clock | | | | | Skew | 1.306
\SPI:BSPIS:es3:SPISlave:BitCounter\/count_3 | \SPI:BSPIS:es3:SPISlave:sR16:Dp:u0\/f1_load | 83.132 MHz | 12.029

Type | Location | Fanout | Instance/Net | Source | Dest | Delay (ns)
count7cell | U(1,0) | 1 | \SPI:BSPIS:es3:SPISlave:BitCounter\ | \SPI:BSPIS:es3:SPISlave:BitCounter\/clock_n | \SPI:BSPIS:es3:SPISlave:BitCounter\/count_3 | 2.110
Route | | 1 | \SPI:BSPIS:es3:SPISlave:count_3\ | \SPI:BSPIS:es3:SPISlave:BitCounter\/count_3 | \SPI:BSPIS:es3:SPISlave:tx_load\/main_0 | 2.705
macrocell11 | U(1,0) | 1 | \SPI:BSPIS:es3:SPISlave:tx_load\ | \SPI:BSPIS:es3:SPISlave:tx_load\/main_0 | \SPI:BSPIS:es3:SPISlave:tx_load\/q | 3.350
Route | | 1 | \SPI:BSPIS:es3:SPISlave:tx_load\ | \SPI:BSPIS:es3:SPISlave:tx_load\/q | \SPI:BSPIS:es3:SPISlave:sR16:Dp:u0\/f1_load | 2.557
datapathcell1 | U(1,0) | 1 | \SPI:BSPIS:es3:SPISlave:sR16:Dp:u0\ | | SETUP | -0.000
Clock | | | | | Skew | 1.307
\SPI:BSPIS:es3:SPISlave:BitCounter\/count_3 | \SPI:BSPIS:es3:SPISlave:sR16:Dp:u1\/f1_load | 83.146 MHz | 12.027

Type | Location | Fanout | Instance/Net | Source | Dest | Delay (ns)
count7cell | U(1,0) | 1 | \SPI:BSPIS:es3:SPISlave:BitCounter\ | \SPI:BSPIS:es3:SPISlave:BitCounter\/clock_n | \SPI:BSPIS:es3:SPISlave:BitCounter\/count_3 | 2.110
Route | | 1 | \SPI:BSPIS:es3:SPISlave:count_3\ | \SPI:BSPIS:es3:SPISlave:BitCounter\/count_3 | \SPI:BSPIS:es3:SPISlave:tx_load\/main_0 | 2.705
macrocell11 | U(1,0) | 1 | \SPI:BSPIS:es3:SPISlave:tx_load\ | \SPI:BSPIS:es3:SPISlave:tx_load\/main_0 | \SPI:BSPIS:es3:SPISlave:tx_load\/q | 3.350
Route | | 1 | \SPI:BSPIS:es3:SPISlave:tx_load\ | \SPI:BSPIS:es3:SPISlave:tx_load\/q | \SPI:BSPIS:es3:SPISlave:sR16:Dp:u1\/f1_load | 2.556
datapathcell2 | U(0,0) | 1 | \SPI:BSPIS:es3:SPISlave:sR16:Dp:u1\ | | SETUP | -0.000
Clock | | | | | Skew | 1.306
\SPI:BSPIS:es3:SPISlave:BitCounter\/count_2 | \SPI:BSPIS:es3:SPISlave:sR16:Dp:u0\/f1_load | 84.126 MHz | 11.887

Type | Location | Fanout | Instance/Net | Source | Dest | Delay (ns)
count7cell | U(1,0) | 1 | \SPI:BSPIS:es3:SPISlave:BitCounter\ | \SPI:BSPIS:es3:SPISlave:BitCounter\/clock_n | \SPI:BSPIS:es3:SPISlave:BitCounter\/count_2 | 2.110
Route | | 1 | \SPI:BSPIS:es3:SPISlave:count_2\ | \SPI:BSPIS:es3:SPISlave:BitCounter\/count_2 | \SPI:BSPIS:es3:SPISlave:tx_load\/main_1 | 2.563
macrocell11 | U(1,0) | 1 | \SPI:BSPIS:es3:SPISlave:tx_load\ | \SPI:BSPIS:es3:SPISlave:tx_load\/main_1 | \SPI:BSPIS:es3:SPISlave:tx_load\/q | 3.350
Route | | 1 | \SPI:BSPIS:es3:SPISlave:tx_load\ | \SPI:BSPIS:es3:SPISlave:tx_load\/q | \SPI:BSPIS:es3:SPISlave:sR16:Dp:u0\/f1_load | 2.557
datapathcell1 | U(1,0) | 1 | \SPI:BSPIS:es3:SPISlave:sR16:Dp:u0\ | | SETUP | -0.000
Clock | | | | | Skew | 1.307
\SPI:BSPIS:es3:SPISlave:BitCounter\/count_2 | \SPI:BSPIS:es3:SPISlave:sR16:Dp:u1\/f1_load | 84.140 MHz | 11.885

Type | Location | Fanout | Instance/Net | Source | Dest | Delay (ns)
count7cell | U(1,0) | 1 | \SPI:BSPIS:es3:SPISlave:BitCounter\ | \SPI:BSPIS:es3:SPISlave:BitCounter\/clock_n | \SPI:BSPIS:es3:SPISlave:BitCounter\/count_2 | 2.110
Route | | 1 | \SPI:BSPIS:es3:SPISlave:count_2\ | \SPI:BSPIS:es3:SPISlave:BitCounter\/count_2 | \SPI:BSPIS:es3:SPISlave:tx_load\/main_1 | 2.563
macrocell11 | U(1,0) | 1 | \SPI:BSPIS:es3:SPISlave:tx_load\ | \SPI:BSPIS:es3:SPISlave:tx_load\/main_1 | \SPI:BSPIS:es3:SPISlave:tx_load\/q | 3.350
Route | | 1 | \SPI:BSPIS:es3:SPISlave:tx_load\ | \SPI:BSPIS:es3:SPISlave:tx_load\/q | \SPI:BSPIS:es3:SPISlave:sR16:Dp:u1\/f1_load | 2.556
datapathcell2 | U(0,0) | 1 | \SPI:BSPIS:es3:SPISlave:sR16:Dp:u1\ | | SETUP | -0.000
Clock | | | | | Skew | 1.306
\SPI:BSPIS:es3:SPISlave:BitCounter\/count_1 | \SPI:BSPIS:es3:SPISlave:sR16:Dp:u0\/f1_load | 84.147 MHz | 11.884

Type | Location | Fanout | Instance/Net | Source | Dest | Delay (ns)
count7cell | U(1,0) | 1 | \SPI:BSPIS:es3:SPISlave:BitCounter\ | \SPI:BSPIS:es3:SPISlave:BitCounter\/clock_n | \SPI:BSPIS:es3:SPISlave:BitCounter\/count_1 | 2.110
Route | | 1 | \SPI:BSPIS:es3:SPISlave:count_1\ | \SPI:BSPIS:es3:SPISlave:BitCounter\/count_1 | \SPI:BSPIS:es3:SPISlave:tx_load\/main_2 | 2.560
macrocell11 | U(1,0) | 1 | \SPI:BSPIS:es3:SPISlave:tx_load\ | \SPI:BSPIS:es3:SPISlave:tx_load\/main_2 | \SPI:BSPIS:es3:SPISlave:tx_load\/q | 3.350
Route | | 1 | \SPI:BSPIS:es3:SPISlave:tx_load\ | \SPI:BSPIS:es3:SPISlave:tx_load\/q | \SPI:BSPIS:es3:SPISlave:sR16:Dp:u0\/f1_load | 2.557
datapathcell1 | U(1,0) | 1 | \SPI:BSPIS:es3:SPISlave:sR16:Dp:u0\ | | SETUP | -0.000
Clock | | | | | Skew | 1.307
\SPI:BSPIS:es3:SPISlave:BitCounter\/count_1 | \SPI:BSPIS:es3:SPISlave:sR16:Dp:u1\/f1_load | 84.161 MHz | 11.882

Type | Location | Fanout | Instance/Net | Source | Dest | Delay (ns)
count7cell | U(1,0) | 1 | \SPI:BSPIS:es3:SPISlave:BitCounter\ | \SPI:BSPIS:es3:SPISlave:BitCounter\/clock_n | \SPI:BSPIS:es3:SPISlave:BitCounter\/count_1 | 2.110
Route | | 1 | \SPI:BSPIS:es3:SPISlave:count_1\ | \SPI:BSPIS:es3:SPISlave:BitCounter\/count_1 | \SPI:BSPIS:es3:SPISlave:tx_load\/main_2 | 2.560
macrocell11 | U(1,0) | 1 | \SPI:BSPIS:es3:SPISlave:tx_load\ | \SPI:BSPIS:es3:SPISlave:tx_load\/main_2 | \SPI:BSPIS:es3:SPISlave:tx_load\/q | 3.350
Route | | 1 | \SPI:BSPIS:es3:SPISlave:tx_load\ | \SPI:BSPIS:es3:SPISlave:tx_load\/q | \SPI:BSPIS:es3:SPISlave:sR16:Dp:u1\/f1_load | 2.556
datapathcell2 | U(0,0) | 1 | \SPI:BSPIS:es3:SPISlave:sR16:Dp:u1\ | | SETUP | -0.000
Clock | | | | | Skew | 1.306

+ Destination Clock : Pin_SCLK(0)/fb : Negative edge

Path Delay Requirement : 83.3333ns

Source | Destination | FMax | Delay (ns) | Slack (ns) | Violation
\SPI:BSPIS:es3:SPISlave:BitCounter\/count_0 | \SPI:BSPIS:es3:SPISlave:sR16:Dp:u0\/route_si | 63.119 MHz | 15.843

Type | Location | Fanout | Instance/Net | Source | Dest | Delay (ns)
count7cell | U(1,0) | 1 | \SPI:BSPIS:es3:SPISlave:BitCounter\ | \SPI:BSPIS:es3:SPISlave:BitCounter\/clock_n | \SPI:BSPIS:es3:SPISlave:BitCounter\/count_0 | 2.110
Route | | 1 | \SPI:BSPIS:es3:SPISlave:count_0\ | \SPI:BSPIS:es3:SPISlave:BitCounter\/count_0 | \SPI:BSPIS:es3:SPISlave:mosi_to_dp\/main_4 | 2.725
macrocell8 | U(1,0) | 1 | \SPI:BSPIS:es3:SPISlave:mosi_to_dp\ | \SPI:BSPIS:es3:SPISlave:mosi_to_dp\/main_4 | \SPI:BSPIS:es3:SPISlave:mosi_to_dp\/q | 3.350
Route | | 1 | \SPI:BSPIS:es3:SPISlave:mosi_to_dp\ | \SPI:BSPIS:es3:SPISlave:mosi_to_dp\/q | \SPI:BSPIS:es3:SPISlave:sR16:Dp:u0\/route_si | 2.701
datapathcell1 | U(1,0) | 1 | \SPI:BSPIS:es3:SPISlave:sR16:Dp:u0\ | | SETUP | 3.650
Clock | | | | | Skew | 1.307
\SPI:BSPIS:es3:SPISlave:BitCounter\/count_3 | \SPI:BSPIS:es3:SPISlave:sR16:Dp:u0\/route_si | 63.199 MHz | 15.823

Type | Location | Fanout | Instance/Net | Source | Dest | Delay (ns)
count7cell | U(1,0) | 1 | \SPI:BSPIS:es3:SPISlave:BitCounter\ | \SPI:BSPIS:es3:SPISlave:BitCounter\/clock_n | \SPI:BSPIS:es3:SPISlave:BitCounter\/count_3 | 2.110
Route | | 1 | \SPI:BSPIS:es3:SPISlave:count_3\ | \SPI:BSPIS:es3:SPISlave:BitCounter\/count_3 | \SPI:BSPIS:es3:SPISlave:mosi_to_dp\/main_1 | 2.705
macrocell8 | U(1,0) | 1 | \SPI:BSPIS:es3:SPISlave:mosi_to_dp\ | \SPI:BSPIS:es3:SPISlave:mosi_to_dp\/main_1 | \SPI:BSPIS:es3:SPISlave:mosi_to_dp\/q | 3.350
Route | | 1 | \SPI:BSPIS:es3:SPISlave:mosi_to_dp\ | \SPI:BSPIS:es3:SPISlave:mosi_to_dp\/q | \SPI:BSPIS:es3:SPISlave:sR16:Dp:u0\/route_si | 2.701
datapathcell1 | U(1,0) | 1 | \SPI:BSPIS:es3:SPISlave:sR16:Dp:u0\ | | SETUP | 3.650
Clock | | | | | Skew | 1.307
\SPI:BSPIS:es3:SPISlave:BitCounter\/count_2 | \SPI:BSPIS:es3:SPISlave:sR16:Dp:u0\/route_si | 63.771 MHz | 15.681

Type | Location | Fanout | Instance/Net | Source | Dest | Delay (ns)
count7cell | U(1,0) | 1 | \SPI:BSPIS:es3:SPISlave:BitCounter\ | \SPI:BSPIS:es3:SPISlave:BitCounter\/clock_n | \SPI:BSPIS:es3:SPISlave:BitCounter\/count_2 | 2.110
Route | | 1 | \SPI:BSPIS:es3:SPISlave:count_2\ | \SPI:BSPIS:es3:SPISlave:BitCounter\/count_2 | \SPI:BSPIS:es3:SPISlave:mosi_to_dp\/main_2 | 2.563
macrocell8 | U(1,0) | 1 | \SPI:BSPIS:es3:SPISlave:mosi_to_dp\ | \SPI:BSPIS:es3:SPISlave:mosi_to_dp\/main_2 | \SPI:BSPIS:es3:SPISlave:mosi_to_dp\/q | 3.350
Route | | 1 | \SPI:BSPIS:es3:SPISlave:mosi_to_dp\ | \SPI:BSPIS:es3:SPISlave:mosi_to_dp\/q | \SPI:BSPIS:es3:SPISlave:sR16:Dp:u0\/route_si | 2.701
datapathcell1 | U(1,0) | 1 | \SPI:BSPIS:es3:SPISlave:sR16:Dp:u0\ | | SETUP | 3.650
Clock | | | | | Skew | 1.307
\SPI:BSPIS:es3:SPISlave:BitCounter\/count_1 | \SPI:BSPIS:es3:SPISlave:sR16:Dp:u0\/route_si | 63.784 MHz | 15.678

Type | Location | Fanout | Instance/Net | Source | Dest | Delay (ns)
count7cell | U(1,0) | 1 | \SPI:BSPIS:es3:SPISlave:BitCounter\ | \SPI:BSPIS:es3:SPISlave:BitCounter\/clock_n | \SPI:BSPIS:es3:SPISlave:BitCounter\/count_1 | 2.110
Route | | 1 | \SPI:BSPIS:es3:SPISlave:count_1\ | \SPI:BSPIS:es3:SPISlave:BitCounter\/count_1 | \SPI:BSPIS:es3:SPISlave:mosi_to_dp\/main_3 | 2.560
macrocell8 | U(1,0) | 1 | \SPI:BSPIS:es3:SPISlave:mosi_to_dp\ | \SPI:BSPIS:es3:SPISlave:mosi_to_dp\/main_3 | \SPI:BSPIS:es3:SPISlave:mosi_to_dp\/q | 3.350
Route | | 1 | \SPI:BSPIS:es3:SPISlave:mosi_to_dp\ | \SPI:BSPIS:es3:SPISlave:mosi_to_dp\/q | \SPI:BSPIS:es3:SPISlave:sR16:Dp:u0\/route_si | 2.701
datapathcell1 | U(1,0) | 1 | \SPI:BSPIS:es3:SPISlave:sR16:Dp:u0\ | | SETUP | 3.650
Clock | | | | | Skew | 1.307
\SPI:BSPIS:es3:SPISlave:BitCounter\/count_0 | \SPI:BSPIS:es3:SPISlave:sR16:Dp:u0\/cs_addr_0 | 65.707 MHz | 15.219

Type | Location | Fanout | Instance/Net | Source | Dest | Delay (ns)
count7cell | U(1,0) | 1 | \SPI:BSPIS:es3:SPISlave:BitCounter\ | \SPI:BSPIS:es3:SPISlave:BitCounter\/clock_n | \SPI:BSPIS:es3:SPISlave:BitCounter\/count_0 | 2.110
Route | | 1 | \SPI:BSPIS:es3:SPISlave:count_0\ | \SPI:BSPIS:es3:SPISlave:BitCounter\/count_0 | \SPI:BSPIS:es3:SPISlave:tx_load\/main_3 | 2.725
macrocell11 | U(1,0) | 1 | \SPI:BSPIS:es3:SPISlave:tx_load\ | \SPI:BSPIS:es3:SPISlave:tx_load\/main_3 | \SPI:BSPIS:es3:SPISlave:tx_load\/q | 3.350
Route | | 1 | \SPI:BSPIS:es3:SPISlave:tx_load\ | \SPI:BSPIS:es3:SPISlave:tx_load\/q | \SPI:BSPIS:es3:SPISlave:sR16:Dp:u0\/cs_addr_0 | 2.557
datapathcell1 | U(1,0) | 1 | \SPI:BSPIS:es3:SPISlave:sR16:Dp:u0\ | | SETUP | 3.170
Clock | | | | | Skew | 1.307
\SPI:BSPIS:es3:SPISlave:BitCounter\/count_0 | \SPI:BSPIS:es3:SPISlave:sR16:Dp:u1\/cs_addr_0 | 65.716 MHz | 15.217

Type | Location | Fanout | Instance/Net | Source | Dest | Delay (ns)
count7cell | U(1,0) | 1 | \SPI:BSPIS:es3:SPISlave:BitCounter\ | \SPI:BSPIS:es3:SPISlave:BitCounter\/clock_n | \SPI:BSPIS:es3:SPISlave:BitCounter\/count_0 | 2.110
Route | | 1 | \SPI:BSPIS:es3:SPISlave:count_0\ | \SPI:BSPIS:es3:SPISlave:BitCounter\/count_0 | \SPI:BSPIS:es3:SPISlave:tx_load\/main_3 | 2.725
macrocell11 | U(1,0) | 1 | \SPI:BSPIS:es3:SPISlave:tx_load\ | \SPI:BSPIS:es3:SPISlave:tx_load\/main_3 | \SPI:BSPIS:es3:SPISlave:tx_load\/q | 3.350
Route | | 1 | \SPI:BSPIS:es3:SPISlave:tx_load\ | \SPI:BSPIS:es3:SPISlave:tx_load\/q | \SPI:BSPIS:es3:SPISlave:sR16:Dp:u1\/cs_addr_0 | 2.556
datapathcell2 | U(0,0) | 1 | \SPI:BSPIS:es3:SPISlave:sR16:Dp:u1\ | | SETUP | 3.170
Clock | | | | | Skew | 1.306
\SPI:BSPIS:es3:SPISlave:BitCounter\/count_3 | \SPI:BSPIS:es3:SPISlave:sR16:Dp:u0\/cs_addr_0 | 65.794 MHz | 15.199

Type | Location | Fanout | Instance/Net | Source | Dest | Delay (ns)
count7cell | U(1,0) | 1 | \SPI:BSPIS:es3:SPISlave:BitCounter\ | \SPI:BSPIS:es3:SPISlave:BitCounter\/clock_n | \SPI:BSPIS:es3:SPISlave:BitCounter\/count_3 | 2.110
Route | | 1 | \SPI:BSPIS:es3:SPISlave:count_3\ | \SPI:BSPIS:es3:SPISlave:BitCounter\/count_3 | \SPI:BSPIS:es3:SPISlave:tx_load\/main_0 | 2.705
macrocell11 | U(1,0) | 1 | \SPI:BSPIS:es3:SPISlave:tx_load\ | \SPI:BSPIS:es3:SPISlave:tx_load\/main_0 | \SPI:BSPIS:es3:SPISlave:tx_load\/q | 3.350
Route | | 1 | \SPI:BSPIS:es3:SPISlave:tx_load\ | \SPI:BSPIS:es3:SPISlave:tx_load\/q | \SPI:BSPIS:es3:SPISlave:sR16:Dp:u0\/cs_addr_0 | 2.557
datapathcell1 | U(1,0) | 1 | \SPI:BSPIS:es3:SPISlave:sR16:Dp:u0\ | | SETUP | 3.170
Clock | | | | | Skew | 1.307
\SPI:BSPIS:es3:SPISlave:BitCounter\/count_3 | \SPI:BSPIS:es3:SPISlave:sR16:Dp:u1\/cs_addr_0 | 65.802 MHz | 15.197

Type | Location | Fanout | Instance/Net | Source | Dest | Delay (ns)
count7cell | U(1,0) | 1 | \SPI:BSPIS:es3:SPISlave:BitCounter\ | \SPI:BSPIS:es3:SPISlave:BitCounter\/clock_n | \SPI:BSPIS:es3:SPISlave:BitCounter\/count_3 | 2.110
Route | | 1 | \SPI:BSPIS:es3:SPISlave:count_3\ | \SPI:BSPIS:es3:SPISlave:BitCounter\/count_3 | \SPI:BSPIS:es3:SPISlave:tx_load\/main_0 | 2.705
macrocell11 | U(1,0) | 1 | \SPI:BSPIS:es3:SPISlave:tx_load\ | \SPI:BSPIS:es3:SPISlave:tx_load\/main_0 | \SPI:BSPIS:es3:SPISlave:tx_load\/q | 3.350
Route | | 1 | \SPI:BSPIS:es3:SPISlave:tx_load\ | \SPI:BSPIS:es3:SPISlave:tx_load\/q | \SPI:BSPIS:es3:SPISlave:sR16:Dp:u1\/cs_addr_0 | 2.556
datapathcell2 | U(0,0) | 1 | \SPI:BSPIS:es3:SPISlave:sR16:Dp:u1\ | | SETUP | 3.170
Clock | | | | | Skew | 1.306
\SPI:BSPIS:es3:SPISlave:BitCounter\/count_2 | \SPI:BSPIS:es3:SPISlave:sR16:Dp:u0\/cs_addr_0 | 66.414 MHz | 15.057

Type | Location | Fanout | Instance/Net | Source | Dest | Delay (ns)
count7cell | U(1,0) | 1 | \SPI:BSPIS:es3:SPISlave:BitCounter\ | \SPI:BSPIS:es3:SPISlave:BitCounter\/clock_n | \SPI:BSPIS:es3:SPISlave:BitCounter\/count_2 | 2.110
Route | | 1 | \SPI:BSPIS:es3:SPISlave:count_2\ | \SPI:BSPIS:es3:SPISlave:BitCounter\/count_2 | \SPI:BSPIS:es3:SPISlave:tx_load\/main_1 | 2.563
macrocell11 | U(1,0) | 1 | \SPI:BSPIS:es3:SPISlave:tx_load\ | \SPI:BSPIS:es3:SPISlave:tx_load\/main_1 | \SPI:BSPIS:es3:SPISlave:tx_load\/q | 3.350
Route | | 1 | \SPI:BSPIS:es3:SPISlave:tx_load\ | \SPI:BSPIS:es3:SPISlave:tx_load\/q | \SPI:BSPIS:es3:SPISlave:sR16:Dp:u0\/cs_addr_0 | 2.557
datapathcell1 | U(1,0) | 1 | \SPI:BSPIS:es3:SPISlave:sR16:Dp:u0\ | | SETUP | 3.170
Clock | | | | | Skew | 1.307
\SPI:BSPIS:es3:SPISlave:BitCounter\/count_2 | \SPI:BSPIS:es3:SPISlave:sR16:Dp:u1\/cs_addr_0 | 66.423 MHz | 15.055

Type | Location | Fanout | Instance/Net | Source | Dest | Delay (ns)
count7cell | U(1,0) | 1 | \SPI:BSPIS:es3:SPISlave:BitCounter\ | \SPI:BSPIS:es3:SPISlave:BitCounter\/clock_n | \SPI:BSPIS:es3:SPISlave:BitCounter\/count_2 | 2.110
Route | | 1 | \SPI:BSPIS:es3:SPISlave:count_2\ | \SPI:BSPIS:es3:SPISlave:BitCounter\/count_2 | \SPI:BSPIS:es3:SPISlave:tx_load\/main_1 | 2.563
macrocell11 | U(1,0) | 1 | \SPI:BSPIS:es3:SPISlave:tx_load\ | \SPI:BSPIS:es3:SPISlave:tx_load\/main_1 | \SPI:BSPIS:es3:SPISlave:tx_load\/q | 3.350
Route | | 1 | \SPI:BSPIS:es3:SPISlave:tx_load\ | \SPI:BSPIS:es3:SPISlave:tx_load\/q | \SPI:BSPIS:es3:SPISlave:sR16:Dp:u1\/cs_addr_0 | 2.556
datapathcell2 | U(0,0) | 1 | \SPI:BSPIS:es3:SPISlave:sR16:Dp:u1\ | | SETUP | 3.170
Clock | | | | | Skew | 1.306

+ Source Clock : SPI_Clock : Positive edge(Required Frequency 12 MHz)

+ Destination Clock : SPI_Clock : Positive edge(Required Frequency 12 MHz)

Path Delay Requirement : 83.3333ns(12 MHz)

Source | Destination | FMax | Delay (ns) | Slack (ns) | Violation
\SPI:BSPIS:es3:SPISlave:sync_1\/out | \SPI:BSPIS:es3:SPISlave:TxStsReg\/status_0 | 86.281 MHz | 11.590 | 71.743
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

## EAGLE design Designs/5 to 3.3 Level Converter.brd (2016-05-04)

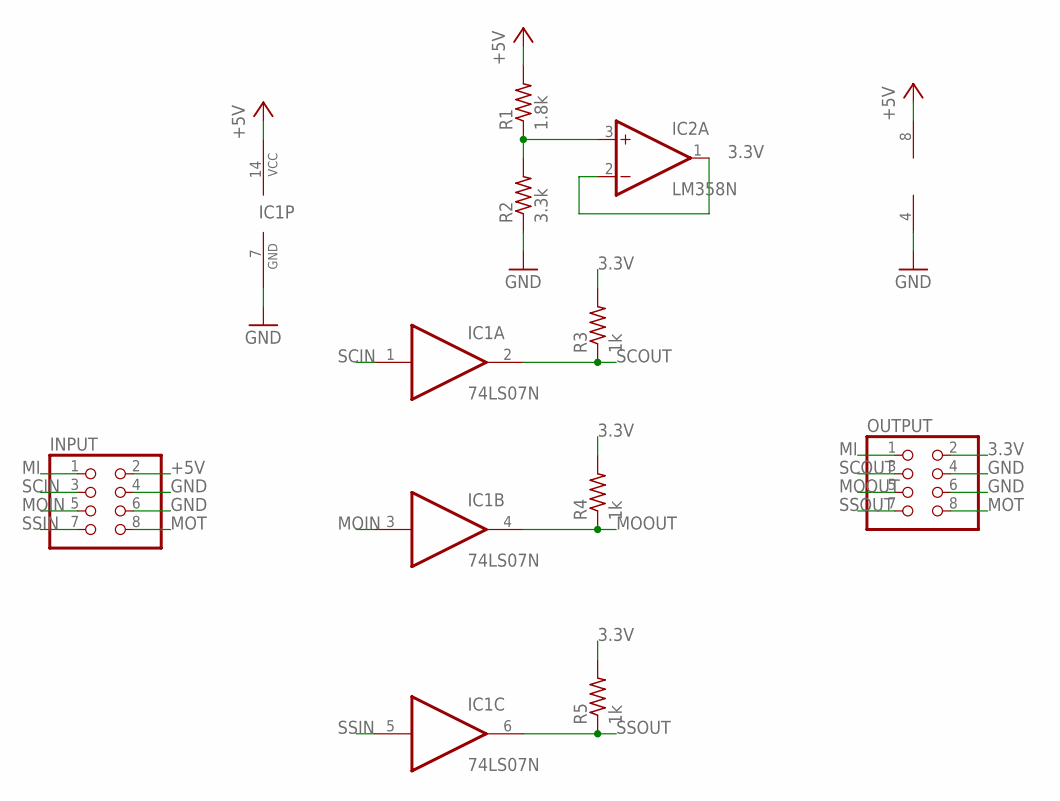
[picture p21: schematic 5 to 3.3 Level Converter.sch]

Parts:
IC1: 74LS07N; DIL14
IC2: LM358N; DIL08
INPUT: PINHD-2X4; 2X04
OUTPUT: PINHD-2X4; 2X04
R1: 1.8k; 0207/7
R2: 3.3k; 0207/7
R3, R4, R5: 1k; 0207/7

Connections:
3.3V: IC2.1 (OUT), IC2.2 (-IN), OUTPUT.2, R3.2, R4.2, R5.2
+5V: IC1.14 (VCC), IC2.8 (V+), INPUT.2, R1.2
GND: IC1.7 (GND), IC2.4 (V-), INPUT.4, INPUT.6, OUTPUT.4, OUTPUT.6, R2.1
MI: INPUT.1, OUTPUT.1
MOIN: IC1.3 (I), INPUT.5
MOOUT: IC1.4 (O), OUTPUT.5, R4.1
MOT: INPUT.8, OUTPUT.8
unnamed: IC2.3 (+IN), R1.1, R2.2
SCIN: IC1.1 (I), INPUT.3
SCOUT: IC1.2 (O), OUTPUT.3, R3.1
SSIN: IC1.5 (I), INPUT.7
SSOUT: IC1.6 (O), OUTPUT.7, R5.1

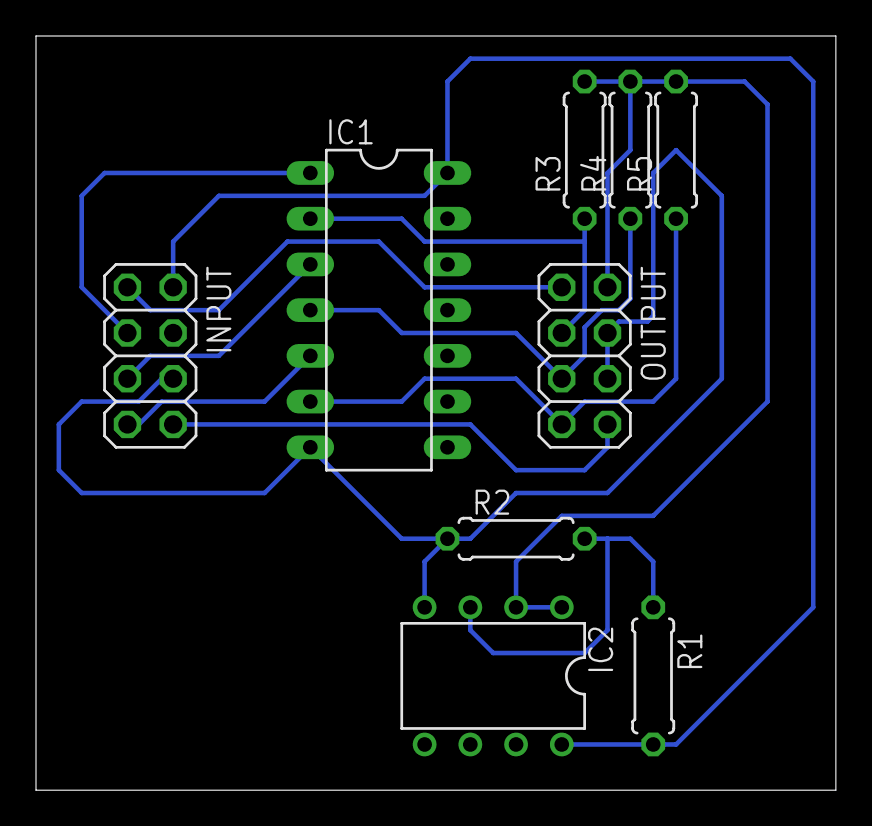
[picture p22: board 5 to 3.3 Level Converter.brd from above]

Board: 2 copper layers, 44.4 x 41.9 mm, 9 parts (0 on the bottom side), 12 nets.

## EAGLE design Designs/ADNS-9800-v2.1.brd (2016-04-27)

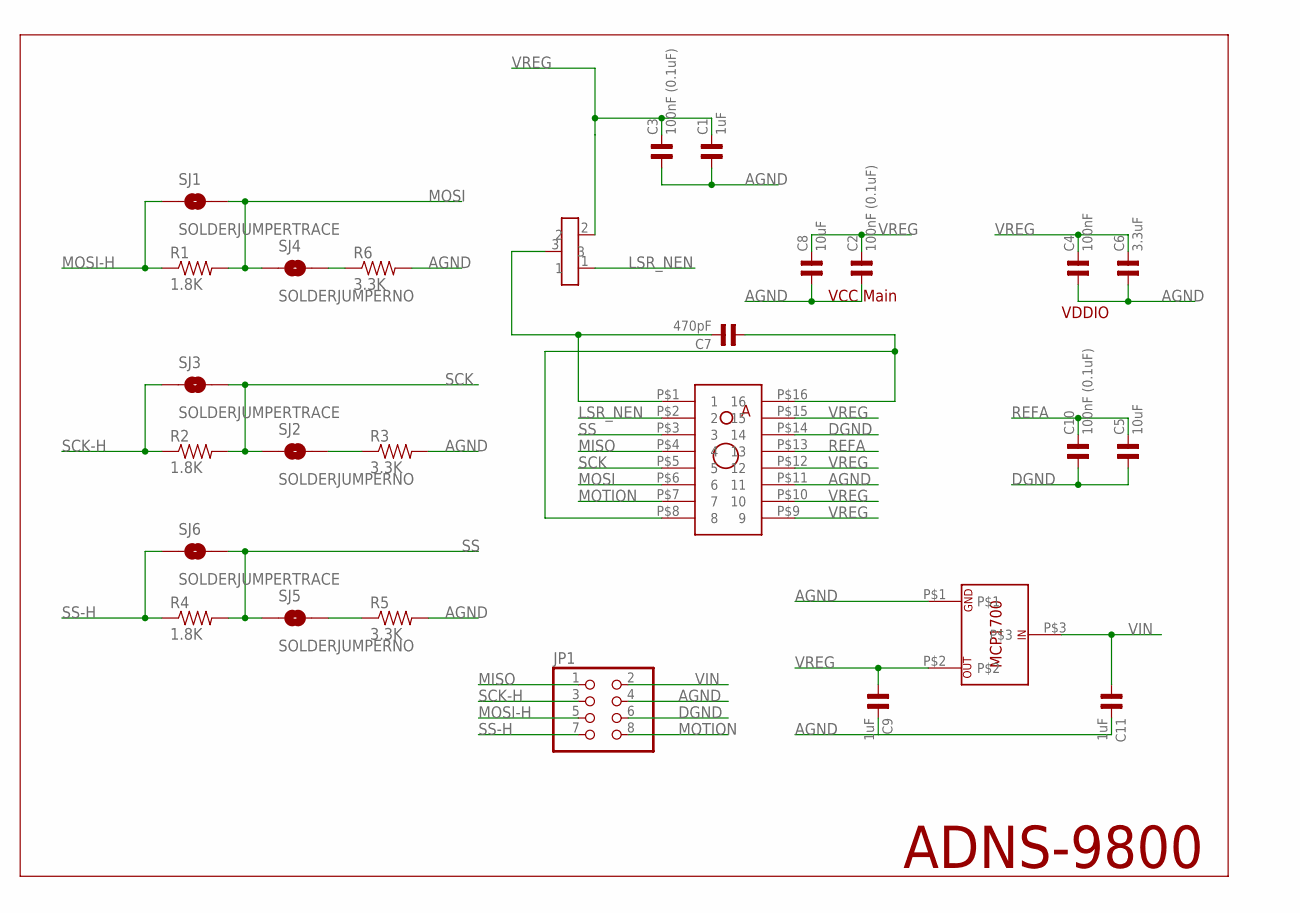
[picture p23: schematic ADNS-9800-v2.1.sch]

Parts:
C1, C9, C11: 1uF; 0603
C2, C3, C10: 100nF (0.1uF); 0603
C4: 100nF; 0603
C5, C8: 10uF; 0603
C6: 3.3uF; 0603
C7: 470pF; 0603
JP1: PINHD-2X4; 2X04
Q1: TRANSISTOR_SC-75; SC-75_TRANSISTOR
R1, R2, R4: 1.8K; 0603-RES
R3, R5, R6: 3.3K; 0603-RES
SJ1, SJ3, SJ6: SOLDERJUMPERTRACE; SJ_2S-TRACE
SJ2, SJ4, SJ5: SOLDERJUMPERNO; SJ_2S-NO
U$1: AVAGO_ADNS-9500
U$2: MCP1700__LDO

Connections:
AGND: C1.1, C2.1, C3.1, C4.1, C6.1, C8.1, C9.2, C11.2, JP1.4, R3.2, R5.2, R6.2, U$1.P$11 (11), U$2.P$1
DGND: C5.1, C10.1, JP1.6, U$1.P$14 (14)
LSR_NEN: Q1.1, U$1.P$2 (2)
MISO: JP1.1, U$1.P$4 (4)
MOSI: R1.2, SJ1.2, SJ4.1, U$1.P$6 (6)
MOSI-H: JP1.5, R1.1, SJ1.1
MOTION: JP1.8, U$1.P$7 (7)
unnamed: C7.1, U$1.P$8 (8), U$1.P$16 (16)
unnamed: C7.2, Q1.3, U$1.P$1 (1)
unnamed: R6.1, SJ4.2
unnamed: R3.1, SJ2.2
unnamed: R5.1, SJ5.2
REFA: C5.2, C10.2, U$1.P$13 (13)
SCK: R2.2, SJ2.1, SJ3.2, U$1.P$5 (5)
SCK-H: JP1.3, R2.1, SJ3.1
SS: R4.2, SJ5.1, SJ6.2, U$1.P$3 (3)
SS-H: JP1.7, R4.1, SJ6.1
VIN: C11.1, JP1.2, U$2.P$3
VREG: C1.2, C2.2, C3.2, C4.2, C6.2, C8.2, C9.1, Q1.2, U$1.P$9 (9), U$1.P$10 (10), U$1.P$12 (12), U$1.P$15 (15), U$2.P$2

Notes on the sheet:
ADNS-9800
VDDIO
VCC Main

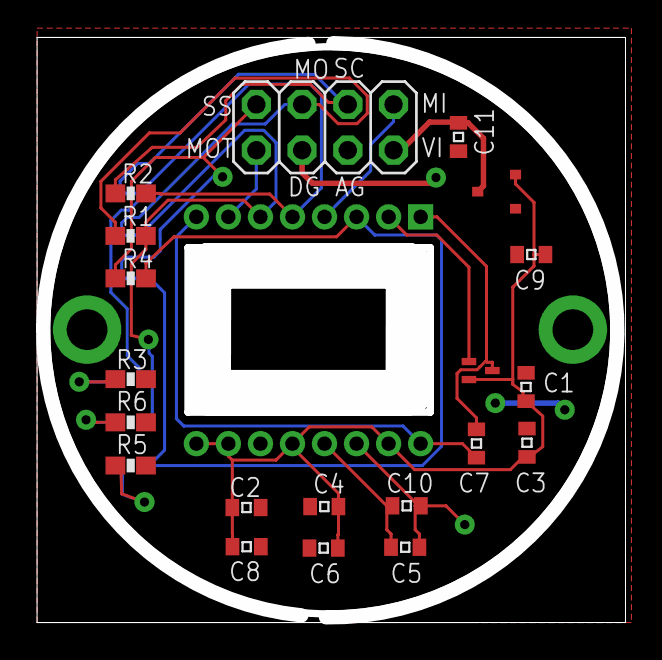
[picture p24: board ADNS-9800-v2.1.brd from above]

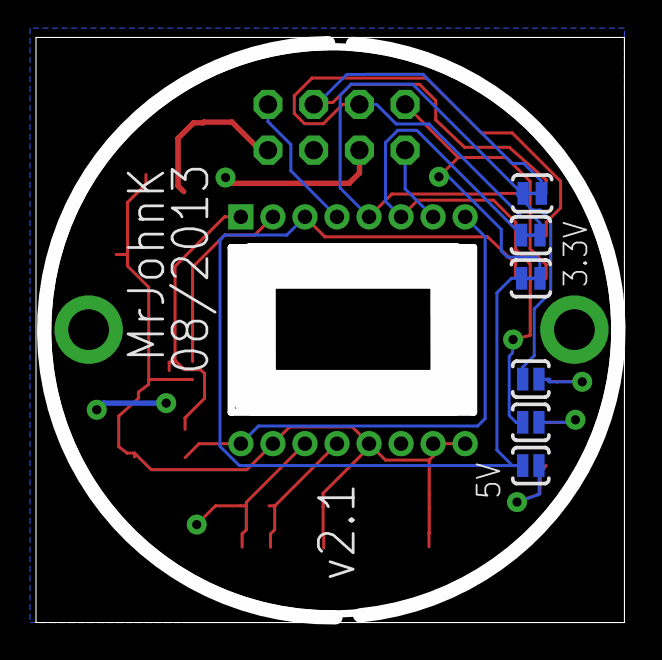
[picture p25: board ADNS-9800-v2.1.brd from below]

Board: 2 copper layers, 32.7 x 32.5 mm, 27 parts (6 on the bottom side), 19 nets.

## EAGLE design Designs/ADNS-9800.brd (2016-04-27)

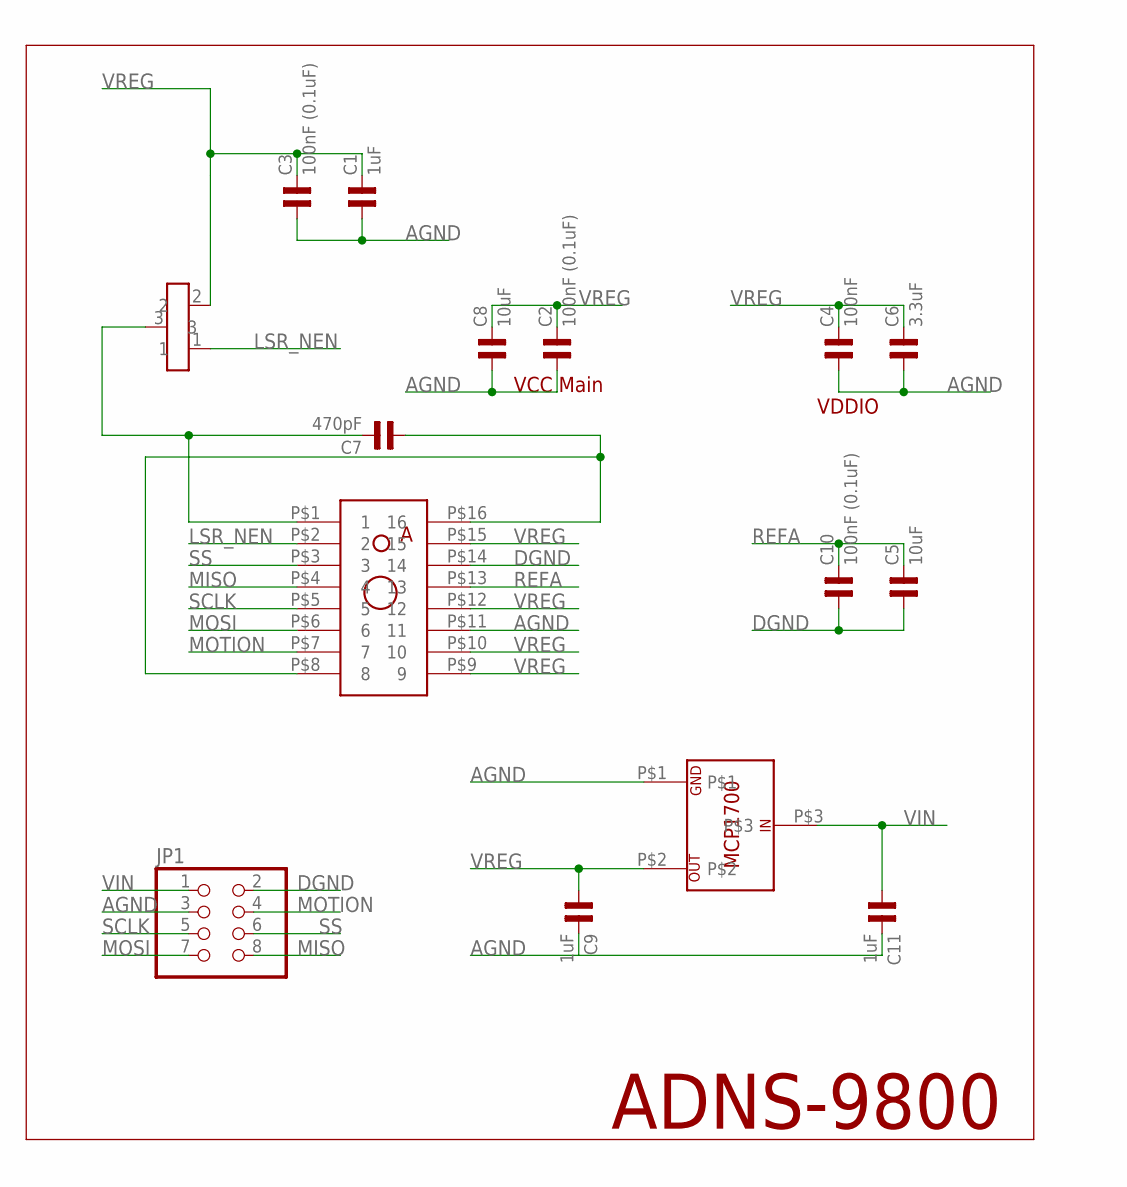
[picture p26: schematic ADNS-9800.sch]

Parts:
C1, C9, C11: 1uF; 0603
C2, C3, C10: 100nF (0.1uF); 0603
C4: 100nF; 0603
C5, C8: 10uF; 0603
C6: 3.3uF; 0603
C7: 470pF; 0603
JP1: PINHD-2X4; 2X04
Q1: TRANSISTOR_SC-75; SC-75_TRANSISTOR
U$1: AVAGO_ADNS-9500
U$2: MCP1700__LDO

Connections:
AGND: C1.1, C2.1, C3.1, C4.1, C6.1, C8.1, C9.2, C11.2, JP1.3, U$1.P$11 (11), U$2.P$1
DGND: C5.1, C10.1, JP1.2, U$1.P$14 (14)
LSR_NEN: Q1.1, U$1.P$2 (2)
MISO: JP1.8, U$1.P$4 (4)
MOSI: JP1.7, U$1.P$6 (6)
MOTION: JP1.4, U$1.P$7 (7)
unnamed: C7.1, U$1.P$8 (8), U$1.P$16 (16)
unnamed: C7.2, Q1.3, U$1.P$1 (1)
REFA: C5.2, C10.2, U$1.P$13 (13)
SCLK: JP1.5, U$1.P$5 (5)
SS: JP1.6, U$1.P$3 (3)
VIN: C11.1, JP1.1, U$2.P$3
VREG: C1.2, C2.2, C3.2, C4.2, C6.2, C8.2, C9.1, Q1.2, U$1.P$9 (9), U$1.P$10 (10), U$1.P$12 (12), U$1.P$15 (15), U$2.P$2

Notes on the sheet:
ADNS-9800
VDDIO
VCC Main

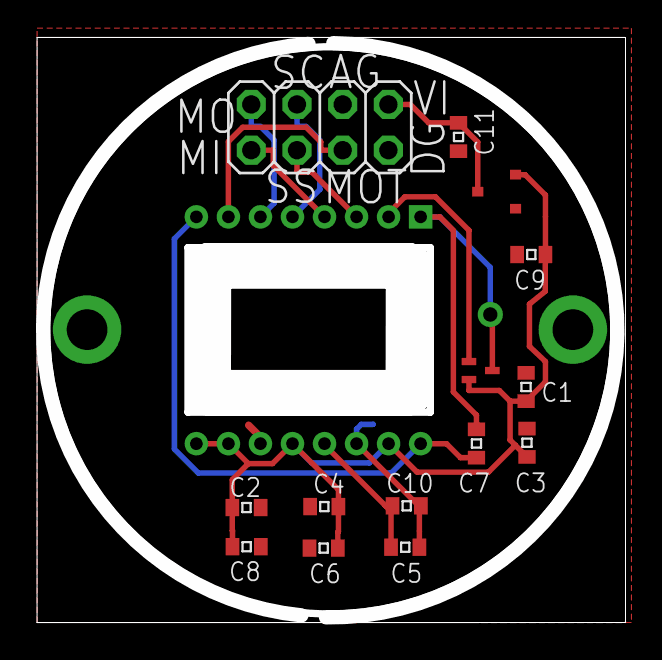
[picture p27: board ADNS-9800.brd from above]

Board: 2 copper layers, 32.7 x 32.5 mm, 15 parts (0 on the bottom side), 13 nets.

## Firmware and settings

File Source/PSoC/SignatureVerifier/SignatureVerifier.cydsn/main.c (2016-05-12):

#include <project.h>
#include <header.h>
#include <stdio.h>

int16 x_position = 0;
int16 y_position = 0;

int16 x_positions_template[256];
int16 y_positions_template[256];
uint16 pos_index_template = 0;

int16 x_positions_test[256];
int16 y_positions_test[256];
uint16 pos_index_test = 0;

uint16 pos_size = 256;

uint8 action_state = RECORDING;
bool reading = false;

uint8 debug_state = LOW;

CY_ISR_PROTO(isr_spi_handler);
CY_ISR_PROTO(isr_button_handler);

void reset_all() {
    // Reset everything back to initial values
    x_position = 0;
    y_position = 0;
    if (action_state == RECORDING) {
        x_positions_template[0] = 0;
        y_positions_template[0] = 0;
        pos_index_template = 1;
    } else {
        x_positions_test[0] = 0;
        y_positions_test[0] = 0;
        pos_index_test = 1;
    }
}

void start_reading() {
    // Tell the desktop we're about to start forging if action_state is FORGING
    if (action_state == FORGING) {
        UART_UartPutString(":F\r\n\0");
    }
}

void stop_reading () {
    char outputString[14];
    int i = 0;
    // Send data to the desktop
    if (action_state == RECORDING) {
        for (i = 0; i < pos_index_template; i++) {
            snprintf(outputString, 14, "%i %i\r\n", x_positions_template[i], y_positions_template[i]);
            UART_UartPutString(outputString);
        }
        UART_UartPutString(":R\r\n\0");
    } else {
        if (action_state == VERIFYING) {
            for (i = 0; i < pos_index_test; i++) {
                snprintf(outputString, 14, "%i %i\r\n", x_positions_test[i], y_positions_test[i]);
                UART_UartPutString(outputString);
            }
            UART_UartPutString(":V\r\n\0");
        }
        UART_UartPutString(":E\r\n\0");
    }
}

CY_ISR(isr_spi_handler) {
    // Get the data that arrives over SPI
    uint16 rxData = SPI_ReadRxData();
    int8 delta_x = (0xf0 | rxData) >> 8;
    int8 delta_y = 0x0f | rxData;
    
    //char outputString[20];
    //snprintf(outputString, 20, ":p_temp %i\r\n", pos_index_template);
    //UART_UartPutString(outputString);
    //snprintf(outputString, 20, ":p_test %i\r\n", pos_index_test);
    //UART_UartPutString(outputString);
    if (reading == true) {
        if ((action_state == RECORDING) && (pos_index_template < pos_size)) {
            // Update x and y positions
            x_position += delta_x;
            y_position += delta_y;
            x_positions_template[pos_index_template] = x_position;
            y_positions_template[pos_index_template] = y_position;
            
            // Update pos_index_template
            pos_index_template++;
        }
        if ((action_state != RECORDING) && (pos_index_test < pos_size)) {
            // Update x and y positions
            x_position += delta_x;
            y_position += delta_y;
            x_positions_test[pos_index_test] = x_position;
            y_positions_test[pos_index_test] = y_position;
            
            // Update pos_index_size
            pos_index_test++;
            
            // Send data to the desktop if action_state is FORGING
            if (action_state == FORGING) {
                char outputString[14];
                snprintf(outputString, 14, "%i %i\r\n", x_position, y_position);
                UART_UartPutString(outputString);
            }
        }
    }
}

CY_ISR(isr_button_handler) {
    // Wait for a bit for the buttons to settle and then read
    CyDelay(1);
    uint8 btn = Pin_Button_Read();
    
    // Change the reading variable to reflect whether the red button is held down or not
    if ((0x1 & btn) == 0 && reading == false) {
        reset_all();
        reading = true;
        start_reading();
    } else if ((0x1 & btn) != 0 && reading == true) {
        reading = false;
        stop_reading();
    }
    
    // Change the action_state to reflect which way the switch is set
    if ((0x2 & btn) == 0) {
        action_state = RECORDING;
    } else if ((0x4 & btn) == 0) {
        action_state = VERIFYING;
    } else {
        action_state = FORGING;
    }
    
    if ((0x8 & btn) == 1) {        
        // Reset everything
        CySoftwareReset();
    }
    
    // Debugging!
    Pin_LED_Debug_Write(debug_state);
    debug_state = HIGH - debug_state;
    
    isr_button_ClearPending();
    Pin_Button_ClearInterrupt();
}

int main()
{
    // Reset everything
    reset_all();
    
    // Start the serial communication systems
    SPI_Start();
    UART_Start();
    
    // Enable interrupts for the SPI system
    SPI_EnableRxInt();
    
    // Enable the isrs
    isr_spi_StartEx(isr_spi_handler);
    isr_button_StartEx(isr_button_handler);
    
    // Enable global interrupts
    CyGlobalIntEnable;
    
    // Debugging!
    Pin_LED_Debug_Write(debug_state);
    debug_state = HIGH - debug_state;
    
    // Chill out
    for(;;) { }
}

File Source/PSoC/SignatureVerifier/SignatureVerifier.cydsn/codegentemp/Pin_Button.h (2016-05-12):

/*******************************************************************************
* File Name: Pin_Button.h  
* Version 2.5
*
* Description:
*  This file containts Control Register function prototypes and register defines
*
* Note:
*
********************************************************************************
* Copyright 2008-2014, Cypress Semiconductor Corporation.  All rights reserved.
* You may use this file only in accordance with the license, terms, conditions, 
* disclaimers, and limitations in the end user license agreement accompanying 
* the software package with which this file was provided.
*******************************************************************************/

#if !defined(CY_PINS_Pin_Button_H) /* Pins Pin_Button_H */
#define CY_PINS_Pin_Button_H

#include "cytypes.h"
#include "cyfitter.h"
#include "Pin_Button_aliases.h"


/***************************************
*        Function Prototypes             
***************************************/    

void    Pin_Button_Write(uint8 value) ;
void    Pin_Button_SetDriveMode(uint8 mode) ;
uint8   Pin_Button_ReadDataReg(void) ;
uint8   Pin_Button_Read(void) ;
uint8   Pin_Button_ClearInterrupt(void) ;


/***************************************
*           API Constants        
***************************************/

/* Drive Modes */
#define Pin_Button_DRIVE_MODE_BITS        (3)
#define Pin_Button_DRIVE_MODE_IND_MASK    (0xFFFFFFFFu >> (32 - Pin_Button_DRIVE_MODE_BITS))
#define Pin_Button_DRIVE_MODE_SHIFT       (0x00u)
#define Pin_Button_DRIVE_MODE_MASK        (0x07u << Pin_Button_DRIVE_MODE_SHIFT)

#define Pin_Button_DM_ALG_HIZ         (0x00u << Pin_Button_DRIVE_MODE_SHIFT)
#define Pin_Button_DM_DIG_HIZ         (0x01u << Pin_Button_DRIVE_MODE_SHIFT)
#define Pin_Button_DM_RES_UP          (0x02u << Pin_Button_DRIVE_MODE_SHIFT)
#define Pin_Button_DM_RES_DWN         (0x03u << Pin_Button_DRIVE_MODE_SHIFT)
#define Pin_Button_DM_OD_LO           (0x04u << Pin_Button_DRIVE_MODE_SHIFT)
#define Pin_Button_DM_OD_HI           (0x05u << Pin_Button_DRIVE_MODE_SHIFT)
#define Pin_Button_DM_STRONG          (0x06u << Pin_Button_DRIVE_MODE_SHIFT)
#define Pin_Button_DM_RES_UPDWN       (0x07u << Pin_Button_DRIVE_MODE_SHIFT)

/* Digital Port Constants */
#define Pin_Button_MASK               Pin_Button__MASK
#define Pin_Button_SHIFT              Pin_Button__SHIFT
#define Pin_Button_WIDTH              4u


/***************************************
*             Registers        
***************************************/

/* Main Port Registers */
/* Pin State */
#define Pin_Button_PS                     (* (reg32 *) Pin_Button__PS)
/* Port Configuration */
#define Pin_Button_PC                     (* (reg32 *) Pin_Button__PC)
/* Data Register */
#define Pin_Button_DR                     (* (reg32 *) Pin_Button__DR)
/* Input Buffer Disable Override */
#define Pin_Button_INP_DIS                (* (reg32 *) Pin_Button__PC2)


#if defined(Pin_Button__INTSTAT)  /* Interrupt Registers */

    #define Pin_Button_INTSTAT                (* (reg32 *) Pin_Button__INTSTAT)

#endif /* Interrupt Registers */

#endif /* End Pins Pin_Button_H */


/* [] END OF FILE */

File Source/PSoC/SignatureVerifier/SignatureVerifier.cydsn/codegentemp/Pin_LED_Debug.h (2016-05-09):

/*******************************************************************************
* File Name: Pin_LED_Debug.h  
* Version 2.5
*
* Description:
*  This file containts Control Register function prototypes and register defines
*
* Note:
*
********************************************************************************
* Copyright 2008-2014, Cypress Semiconductor Corporation.  All rights reserved.
* You may use this file only in accordance with the license, terms, conditions, 
* disclaimers, and limitations in the end user license agreement accompanying 
* the software package with which this file was provided.
*******************************************************************************/

#if !defined(CY_PINS_Pin_LED_Debug_H) /* Pins Pin_LED_Debug_H */
#define CY_PINS_Pin_LED_Debug_H

#include "cytypes.h"
#include "cyfitter.h"
#include "Pin_LED_Debug_aliases.h"


/***************************************
*        Function Prototypes             
***************************************/    

void    Pin_LED_Debug_Write(uint8 value) ;
void    Pin_LED_Debug_SetDriveMode(uint8 mode) ;
uint8   Pin_LED_Debug_ReadDataReg(void) ;
uint8   Pin_LED_Debug_Read(void) ;
uint8   Pin_LED_Debug_ClearInterrupt(void) ;


/***************************************
*           API Constants        
***************************************/

/* Drive Modes */
#define Pin_LED_Debug_DRIVE_MODE_BITS        (3)
#define Pin_LED_Debug_DRIVE_MODE_IND_MASK    (0xFFFFFFFFu >> (32 - Pin_LED_Debug_DRIVE_MODE_BITS))
#define Pin_LED_Debug_DRIVE_MODE_SHIFT       (0x00u)
#define Pin_LED_Debug_DRIVE_MODE_MASK        (0x07u << Pin_LED_Debug_DRIVE_MODE_SHIFT)

#define Pin_LED_Debug_DM_ALG_HIZ         (0x00u << Pin_LED_Debug_DRIVE_MODE_SHIFT)
#define Pin_LED_Debug_DM_DIG_HIZ         (0x01u << Pin_LED_Debug_DRIVE_MODE_SHIFT)
#define Pin_LED_Debug_DM_RES_UP          (0x02u << Pin_LED_Debug_DRIVE_MODE_SHIFT)
#define Pin_LED_Debug_DM_RES_DWN         (0x03u << Pin_LED_Debug_DRIVE_MODE_SHIFT)
#define Pin_LED_Debug_DM_OD_LO           (0x04u << Pin_LED_Debug_DRIVE_MODE_SHIFT)
#define Pin_LED_Debug_DM_OD_HI           (0x05u << Pin_LED_Debug_DRIVE_MODE_SHIFT)
#define Pin_LED_Debug_DM_STRONG          (0x06u << Pin_LED_Debug_DRIVE_MODE_SHIFT)
#define Pin_LED_Debug_DM_RES_UPDWN       (0x07u << Pin_LED_Debug_DRIVE_MODE_SHIFT)

/* Digital Port Constants */
#define Pin_LED_Debug_MASK               Pin_LED_Debug__MASK
#define Pin_LED_Debug_SHIFT              Pin_LED_Debug__SHIFT
#define Pin_LED_Debug_WIDTH              1u


/***************************************
*             Registers        
***************************************/

/* Main Port Registers */
/* Pin State */
#define Pin_LED_Debug_PS                     (* (reg32 *) Pin_LED_Debug__PS)
/* Port Configuration */
#define Pin_LED_Debug_PC                     (* (reg32 *) Pin_LED_Debug__PC)
/* Data Register */
#define Pin_LED_Debug_DR                     (* (reg32 *) Pin_LED_Debug__DR)
/* Input Buffer Disable Override */
#define Pin_LED_Debug_INP_DIS                (* (reg32 *) Pin_LED_Debug__PC2)


#if defined(Pin_LED_Debug__INTSTAT)  /* Interrupt Registers */

    #define Pin_LED_Debug_INTSTAT                (* (reg32 *) Pin_LED_Debug__INTSTAT)

#endif /* Interrupt Registers */

#endif /* End Pins Pin_LED_Debug_H */


/* [] END OF FILE */

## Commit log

2016-04-18 Made first (untested) prototype of ADNS-9800 REPL
2016-04-20 Rearranged files, added datasheets, made a schematic, started PSoC project
    [ADNS-9800.sch, Whole Board.sch]
2016-04-21 Modified source to be able to target different MCS-51 microcontrollers
    [Whole Board.sch]
2016-04-24 First mechanical prototypes
    [Base.SLDPRT, Body.SLDPRT, Probe.SLDASM]
2016-04-25 Minor changes to mechanicals
    [Body.SLDPRT, Probe.SLDASM]
2016-04-27 Added boards and schematics for ADNS-9800 breakout board
    [ADNS-9800-v2.1.brd, ADNS-9800-v2.1.sch, ADNS-9800.brd]
2016-05-03 Did testing work for motion.asm
    [5 to 3.3 Level Converter.sch]
2016-05-04 Made level converter Eagle file, minor changes to motion.asm and psoc.lib.asm
    [5 to 3.3 Level Converter.brd, 5 to 3.3 Level Converter.sch, Base.SLDPRT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]
2016-05-05 Started work on PSoC component
    [Base.SLDPRT, Base.STL, SignatureVerifier.sdf]
2016-05-08 Did some work on design, PSoC, motion.asm, and desktop MATLAB interface
    [Base.SLDPRT, Base.STL, Body.SLDPRT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]
2016-05-09 Got SPI communication with PSoC working
2016-05-09 Got PSoC to send data to MATLAB
    [SignatureVerifier.sdf]
2016-05-09 Added SPI interrupts to PSoC code
    [SignatureVerifier.sdf]
2016-05-10 Got interrupts on PSoC working with switches and buttons
    [SignatureVerifier.sdf]
2016-05-11 Made PSoC talk to MATLAB to visualize signature
    [Base.SLDPRT, Full Probe.SLDASM, Probe Left.SLDPRT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]
2016-05-12 Got signature verify to work and signature forge to implement a simple algorithm but not really work
    [SignatureVerifier.sdf]

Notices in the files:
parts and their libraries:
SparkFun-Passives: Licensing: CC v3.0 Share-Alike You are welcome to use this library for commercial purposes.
